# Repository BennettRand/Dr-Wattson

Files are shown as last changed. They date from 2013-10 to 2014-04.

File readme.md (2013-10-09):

#Dr. Wattson: Power Inspector#

##Project Description##
Dr. Wattson: Power Analyzer is an integrated system which aims brings real time data collection and analysis of home energy usage to consumers in an easy and understandable way. Presently, average consumers do not have the tools to make informed decisions about their energy consumption. The goal of the Dr. Wattson project is to help consumers evaluate their current energy consumption habits and provide them with recommendations to help them improve their energy footprint. Installation of the Dr. Wattson distributed network of distributed power monitors will be a simple plug and play process, making it simple to use for consumers of all technical abilities. Dr. Wattson will collect and process the user’s energy use habits and present them with easy to understand graphs, comparisons, and suggestions to help them save energy and money. Additionally, the user will be able to upload and compare their energy data with others via social networking.

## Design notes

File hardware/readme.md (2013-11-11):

##Hardware Files##
This directory is for storing the PCB design and schematic files.

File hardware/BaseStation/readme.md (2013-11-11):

##Hardware Files - Base Station##
PCB design files for the base station.

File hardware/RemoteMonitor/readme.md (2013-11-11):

##Hardware Files - Remote Monitoring Unit##
This is where we will store the design files for the remote monitoring unit PCB.

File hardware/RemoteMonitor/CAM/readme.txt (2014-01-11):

Remote Monitoring Unit PCB Design
Engineering Contact: Kit Morton <mortonki@onid.oregonstate.edu>
Board Outline is in top silkscreen layer (remoteMonitor.GTO)

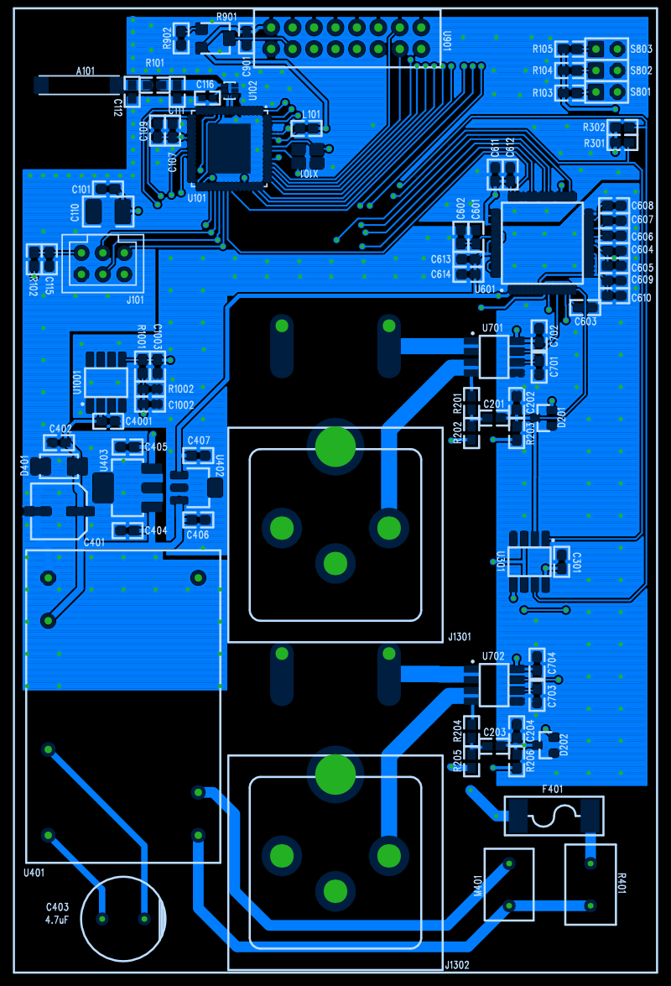
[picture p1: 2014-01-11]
hardware/RemoteMonitor/CAM/remoteMonitorTopLayer.png

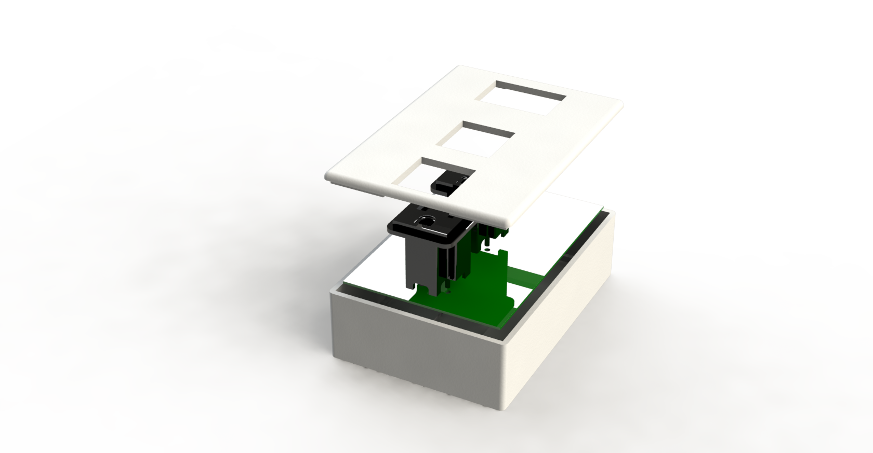
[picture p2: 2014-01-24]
hardware/RemoteMonitor/Case/exploded.png

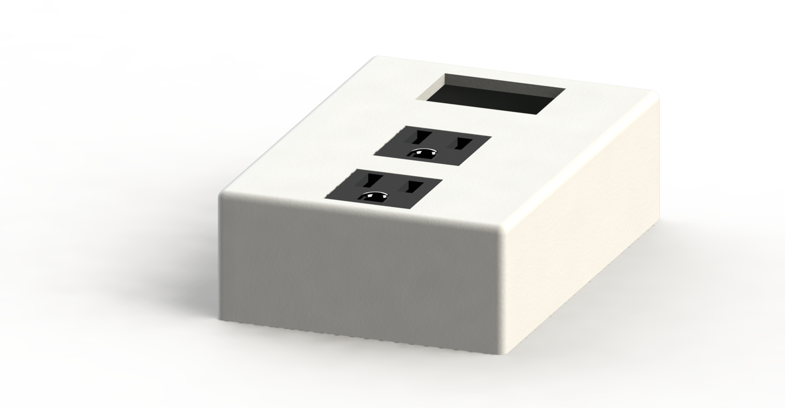
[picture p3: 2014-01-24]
hardware/RemoteMonitor/Case/case.png

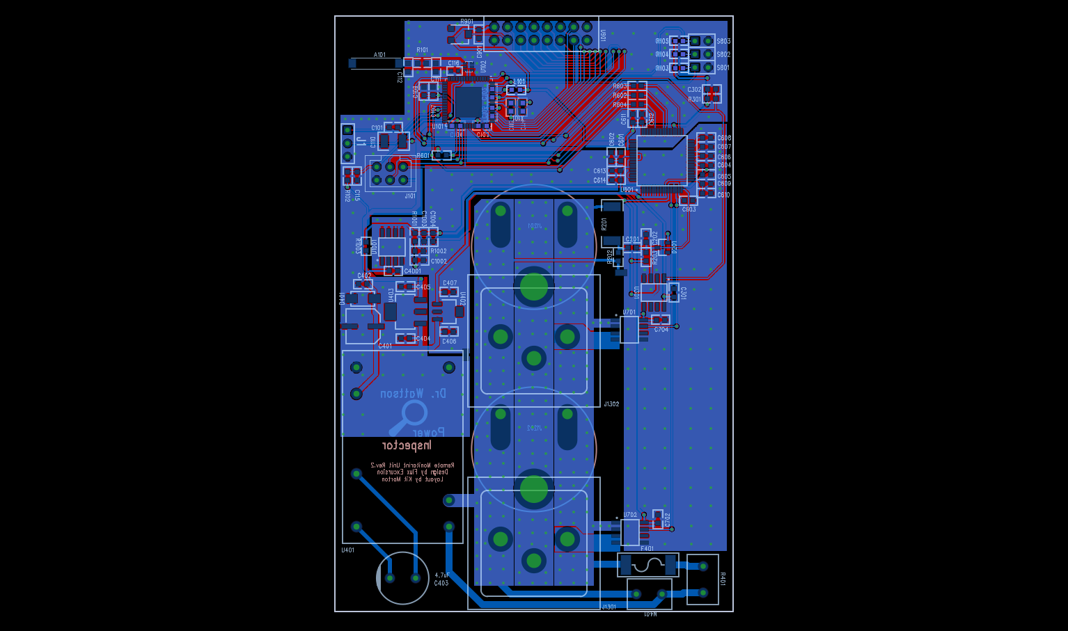
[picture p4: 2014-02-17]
hardware/RemoteMonitor/CAM/all_layers.png

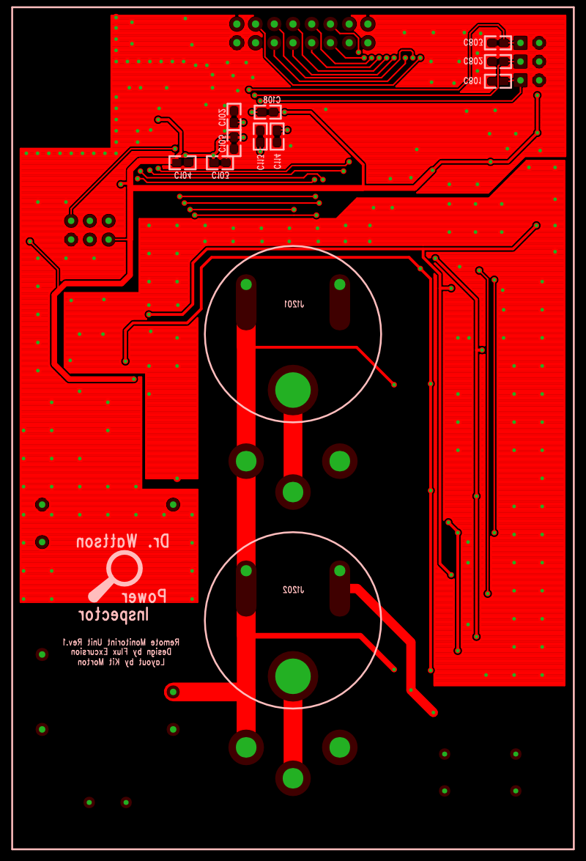
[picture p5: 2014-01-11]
hardware/RemoteMonitor/CAM/remoteMonitorBottomLayer.png

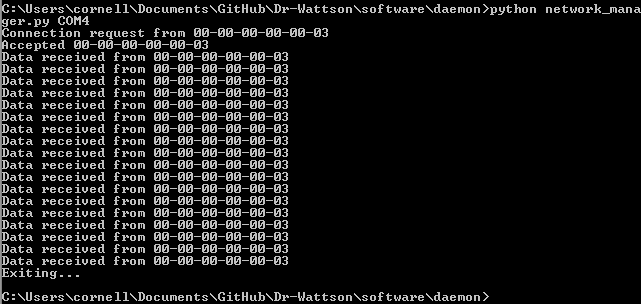
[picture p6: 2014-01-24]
software/daemon/console_demo.PNG

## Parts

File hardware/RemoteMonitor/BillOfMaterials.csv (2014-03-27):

Item | Qty | Reference | Part Name | Manufacturer | Description
1 | 1 | A101 | 2450AT45A100E
2 | 1 | U102 | 2450FB15L0001
3 | 1 | F401 | 3403.0163.11
4 | 3 | S801-803 | 40-4520-00
5 | 2 | U701-702 | ACS712
6 | 1 | U601 | ADS130E08IPAG
7 | 1 | U101 | ATMEGA256RFR2
8 | 1 | R401 | B57235S100M54
9 | 2 | D201-202 | BAT54S
10 | 1 | C116 | CAP0402 | 22pF | IPC SM-782 STD. | SURFACE MOUNT CAPACITOR 0.031 X 0.061 INCHES
11 | 20 | C101-102 C201 C203 C301 C402 C602-604 C610 C612-613 C702 C704 C801-803 C901 C1003 C4001 | CAP0603 | 0.1uF | IPC SM-782 STD. | SURFACE MOUNT CAPACITOR 0.031 X 0.061 INCHES
12 | 1 | C302 | CAP0603 | 10nF | IPC SM-782 STD. | SURFACE MOUNT CAPACITOR 0.031 X 0.061 INCHES
13 | 1 | C605 | CAP0603 | 10uF | IPC SM-782 STD. | SURFACE MOUNT CAPACITOR 0.031 X 0.061 INCHES
14 | 3 | C113-115 | CAP0603 | 16pF | IPC SM-782 STD. | SURFACE MOUNT CAPACITOR 0.031 X 0.061 INCHES
15 | 18 | C103-105 C107-109 C404-407 C601 C606 C608-609 C611 C614 C1002 C1004 | CAP0603 | 1uF | IPC SM-782 STD. | SURFACE MOUNT CAPACITOR 0.031 X 0.061 INCHES
16 | 1 | C607 | CAP0603 | 22uF | IPC SM-782 STD. | SURFACE MOUNT CAPACITOR 0.031 X 0.061 INCHES
17 | 2 | C202 C204 | CAP0603 | 4.7nF | IPC SM-782 STD. | SURFACE MOUNT CAPACITOR 0.031 X 0.061 INCHES
18 | 2 | C111-112 | CAP0603 | N/A | IPC SM-782 STD. | SURFACE MOUNT CAPACITOR 0.031 X 0.061 INCHES
19 | 1 | C110 | CAP1210 | 47uF | IPC SM-782 STD. | SURFACE MOUNT CAPACITOR 0.098 X 0.126 INCHES
20 | 1 | C403 | CAP-D10P | 4.7uF
21 | 1 | C401 | EEE-FTV151 | 150uF
22 | 1 | M401 | ERZ-V07D471
23 | 1 | L101 | FERRITE
24 | 1 | J1 | HEADER03 |  | THREE PIN INLINE HEADER; 100 MIL CENTERS
25 | 1 | J101 | ISP_HEADER
26 | 1 | U402 | L78L05
27 | 1 | U301 | LM2903-TI
28 | 2 | J1301-1302 | NEMA-5-15R
29 | 2 | J1201-1202 | NEMA5-15P
30 | 1 | U901 | NHD-0208AZ-RN-YBW-33V
31 | 1 | D401 | P4SMA20A
32 | 1 | R901 | PVG3A | 10K
33 | 1 | U1001 | REF02BU
34 | 1 | R101 | RES0603 | 0 | IPC SM-782 STD. | SURFACE MOUNT RESISTOR 0.031 X 0.061 INCHES | 1/10W
35 | 6 | R102-105 R301 R601 | RES0603 | 10K | IPC SM-782 STD. | SURFACE MOUNT RESISTOR 0.031 X 0.061 INCHES | 1/10W
36 | 2 | R203 R206 | RES0603 | 1M | IPC SM-782 STD. | SURFACE MOUNT RESISTOR 0.031 X 0.061 INCHES | 1/10W
37 | 2 | R1001-1002 | RES0603 | 2.2k | IPC SM-782 STD. | SURFACE MOUNT RESISTOR 0.031 X 0.061 INCHES | 1/10W
38 | 2 | R202 R205 | RES0603 | 2K | IPC SM-782 STD. | SURFACE MOUNT RESISTOR 0.031 X 0.061 INCHES | 1/10W
39 | 1 | R1003 | RES0603 | 330 | IPC SM-782 STD. | SURFACE MOUNT RESISTOR 0.031 X 0.061 INCHES | 1/10W
40 | 2 | R602-603 | RES0603 | 470 | IPC SM-782 STD. | SURFACE MOUNT RESISTOR 0.031 X 0.061 INCHES | 1/10W
41 | 2 | R201 R204 | RES2512 | 330K | IPC SM-782 STD. | SURFACE MOUNT RESISTOR 0.126 X 0.248 INCHES | 1W
42 | 3 | S1-3 | SHORT
43 | 1 | X101 | TSX-3225_16.0000
44 | 1 | U403 | UA78M33
45 | 1 | U401 | VSK-S3-12U

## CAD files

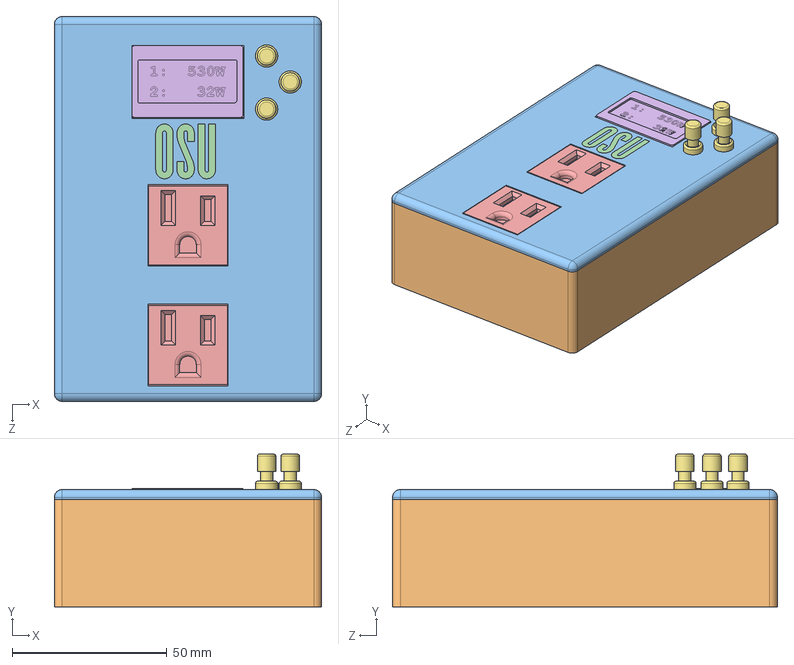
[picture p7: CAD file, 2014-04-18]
hardware/RemoteMonitor/Case/case.SLDASM
86.4 x 49.4 x 124.3 mm
pcb
base
cover
logo
plug x 2
Screen
Switch x 3

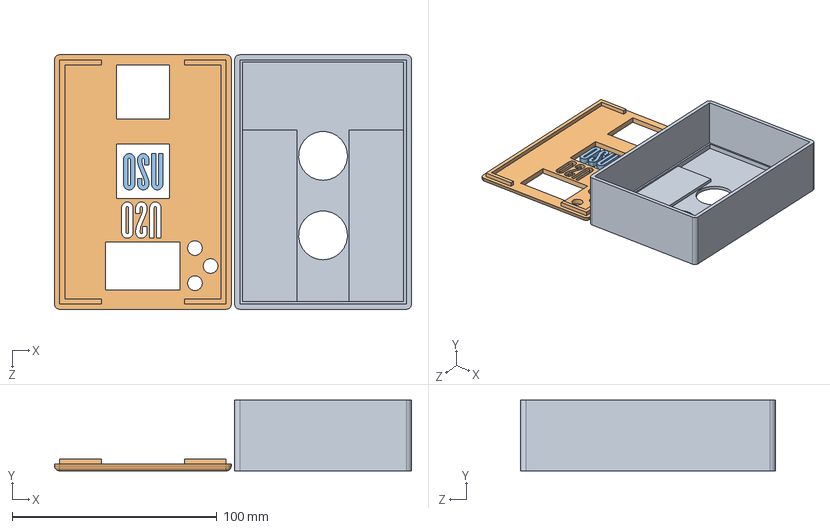
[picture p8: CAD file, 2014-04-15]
hardware/RemoteMonitor/Case/printed.SLDASM
174.3 x 34.6 x 124.3 mm
base
cover
logo

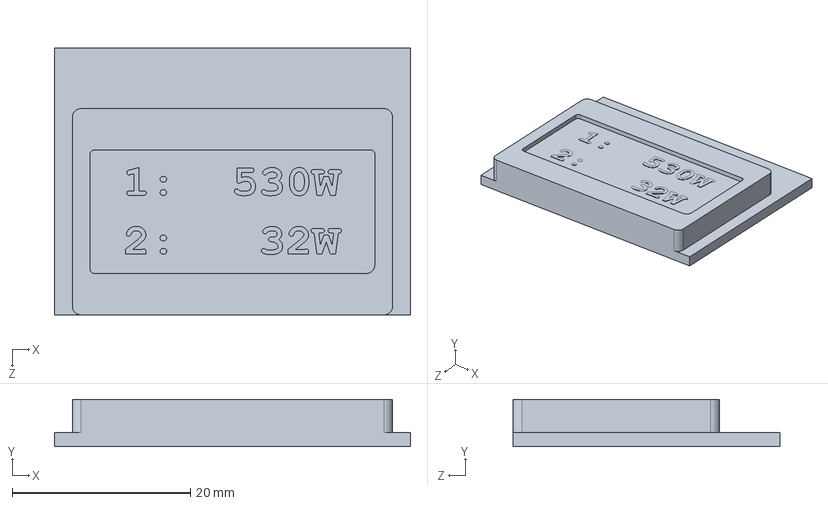
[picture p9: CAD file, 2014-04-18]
hardware/RemoteMonitor/Case/Screen.SLDPRT
40.0 x 5.30 x 30.0 mm

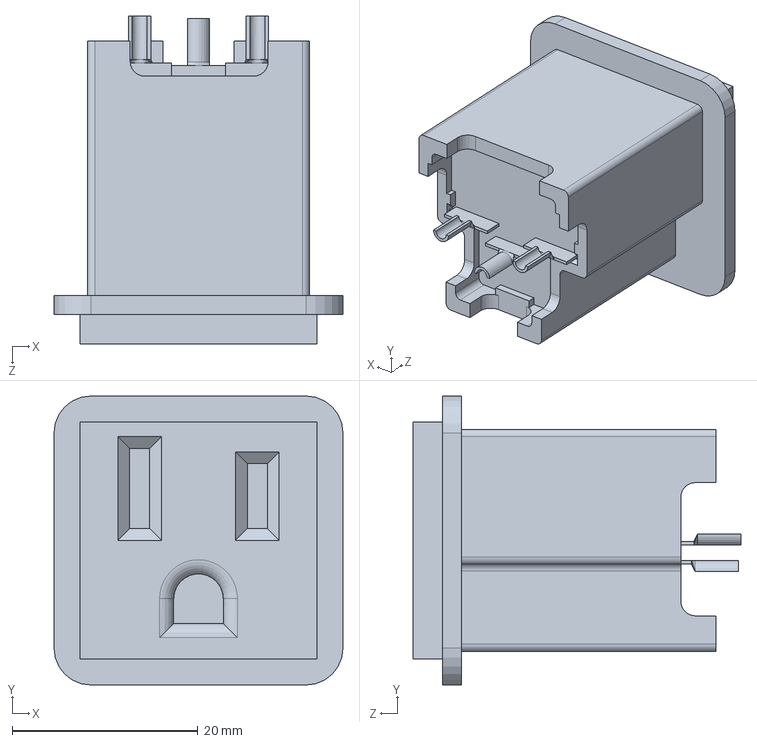
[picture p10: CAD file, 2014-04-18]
hardware/RemoteMonitor/Case/plug.SLDPRT
31.1 x 31.1 x 35.3 mm

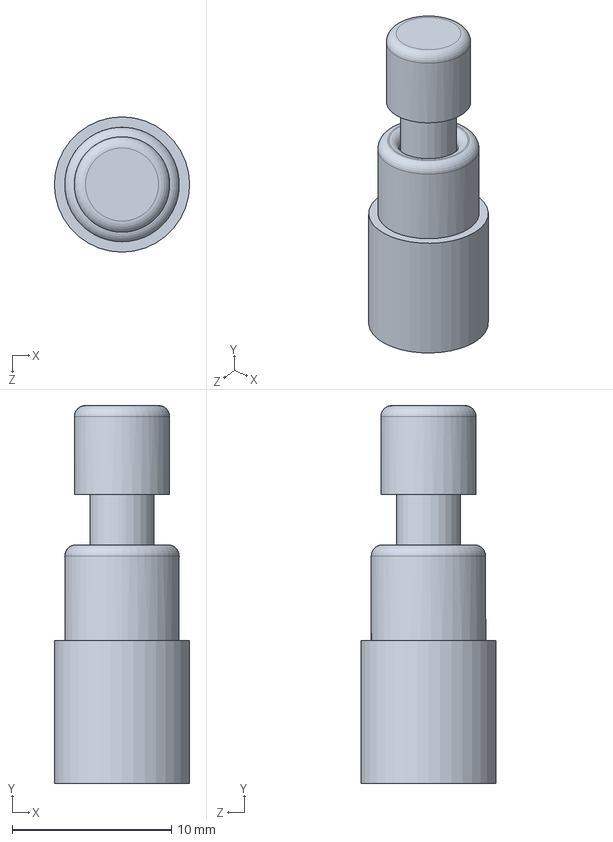
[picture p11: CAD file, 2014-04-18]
hardware/RemoteMonitor/Case/Switch.SLDPRT
8.50 x 23.8 x 8.50 mm

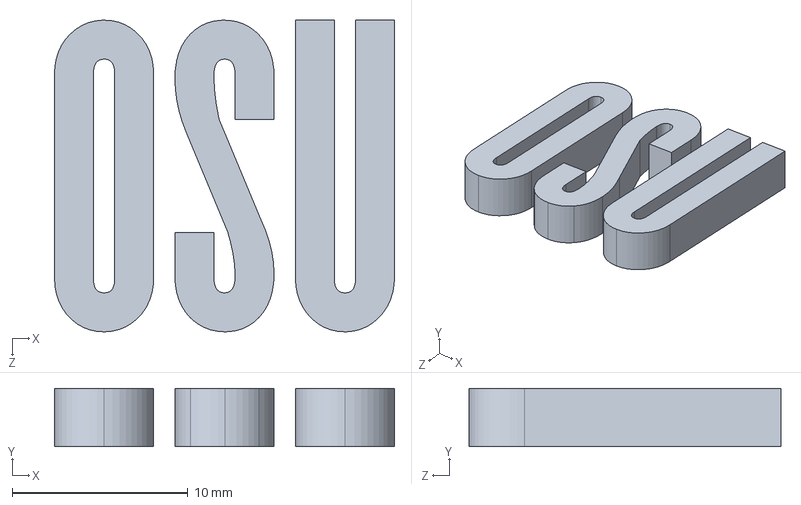
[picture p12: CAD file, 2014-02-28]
hardware/RemoteMonitor/Case/logo.SLDPRT
19.3 x 3.30 x 17.7 mm

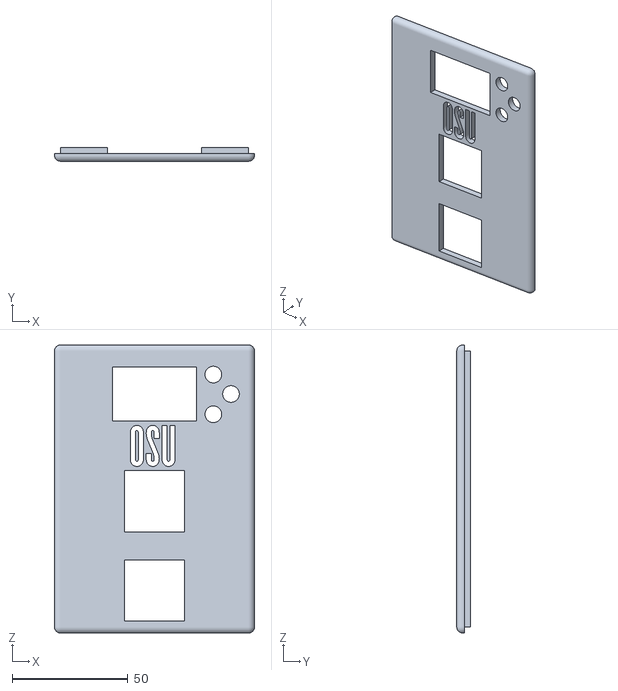
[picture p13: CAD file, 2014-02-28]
hardware/RemoteMonitor/Case/printed - cover-1.STL
86.4 x 5.84 x 124.3

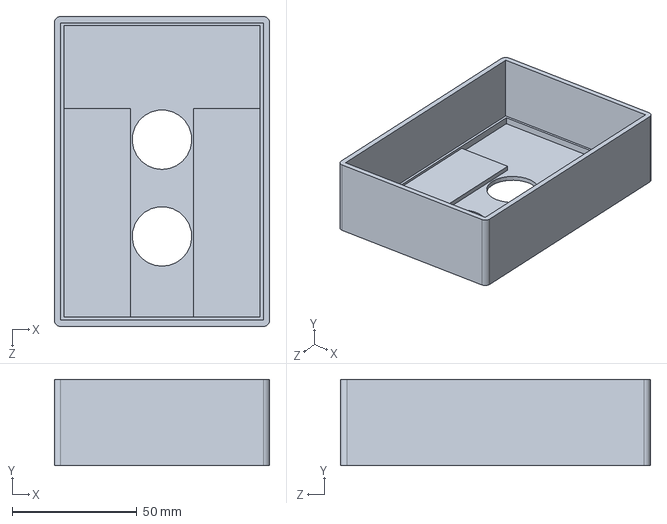
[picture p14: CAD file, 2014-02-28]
hardware/RemoteMonitor/Case/base.SLDPRT
86.4 x 34.6 x 124.3 mm

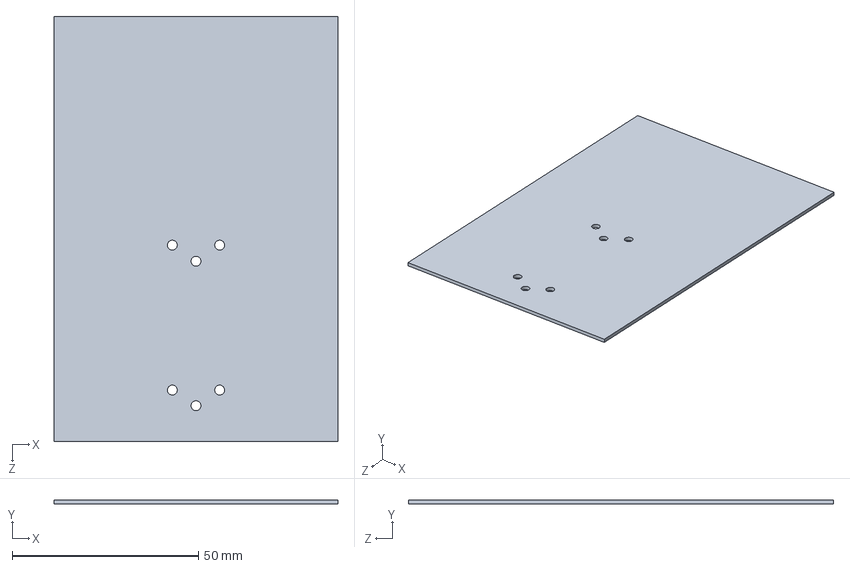
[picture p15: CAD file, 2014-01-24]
hardware/RemoteMonitor/Case/pcb.SLDPRT
76.2 x 1.12 x 114.2 mm

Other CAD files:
hardware/RemoteMonitor/Case/cover.SLDPRT
hardware/RemoteMonitor/Case/printed - logo-1.STL
hardware/RemoteMonitor/Case/printed - base-1.STL
hardware/RemoteMonitor/Case/c-3-213598-2-m-3d.stp
hardware/RemoteMonitor/Case/printed.STL

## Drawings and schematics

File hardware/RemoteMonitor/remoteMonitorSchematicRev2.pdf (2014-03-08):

D

6 | 5 | 4 | 3 | 2 | 1

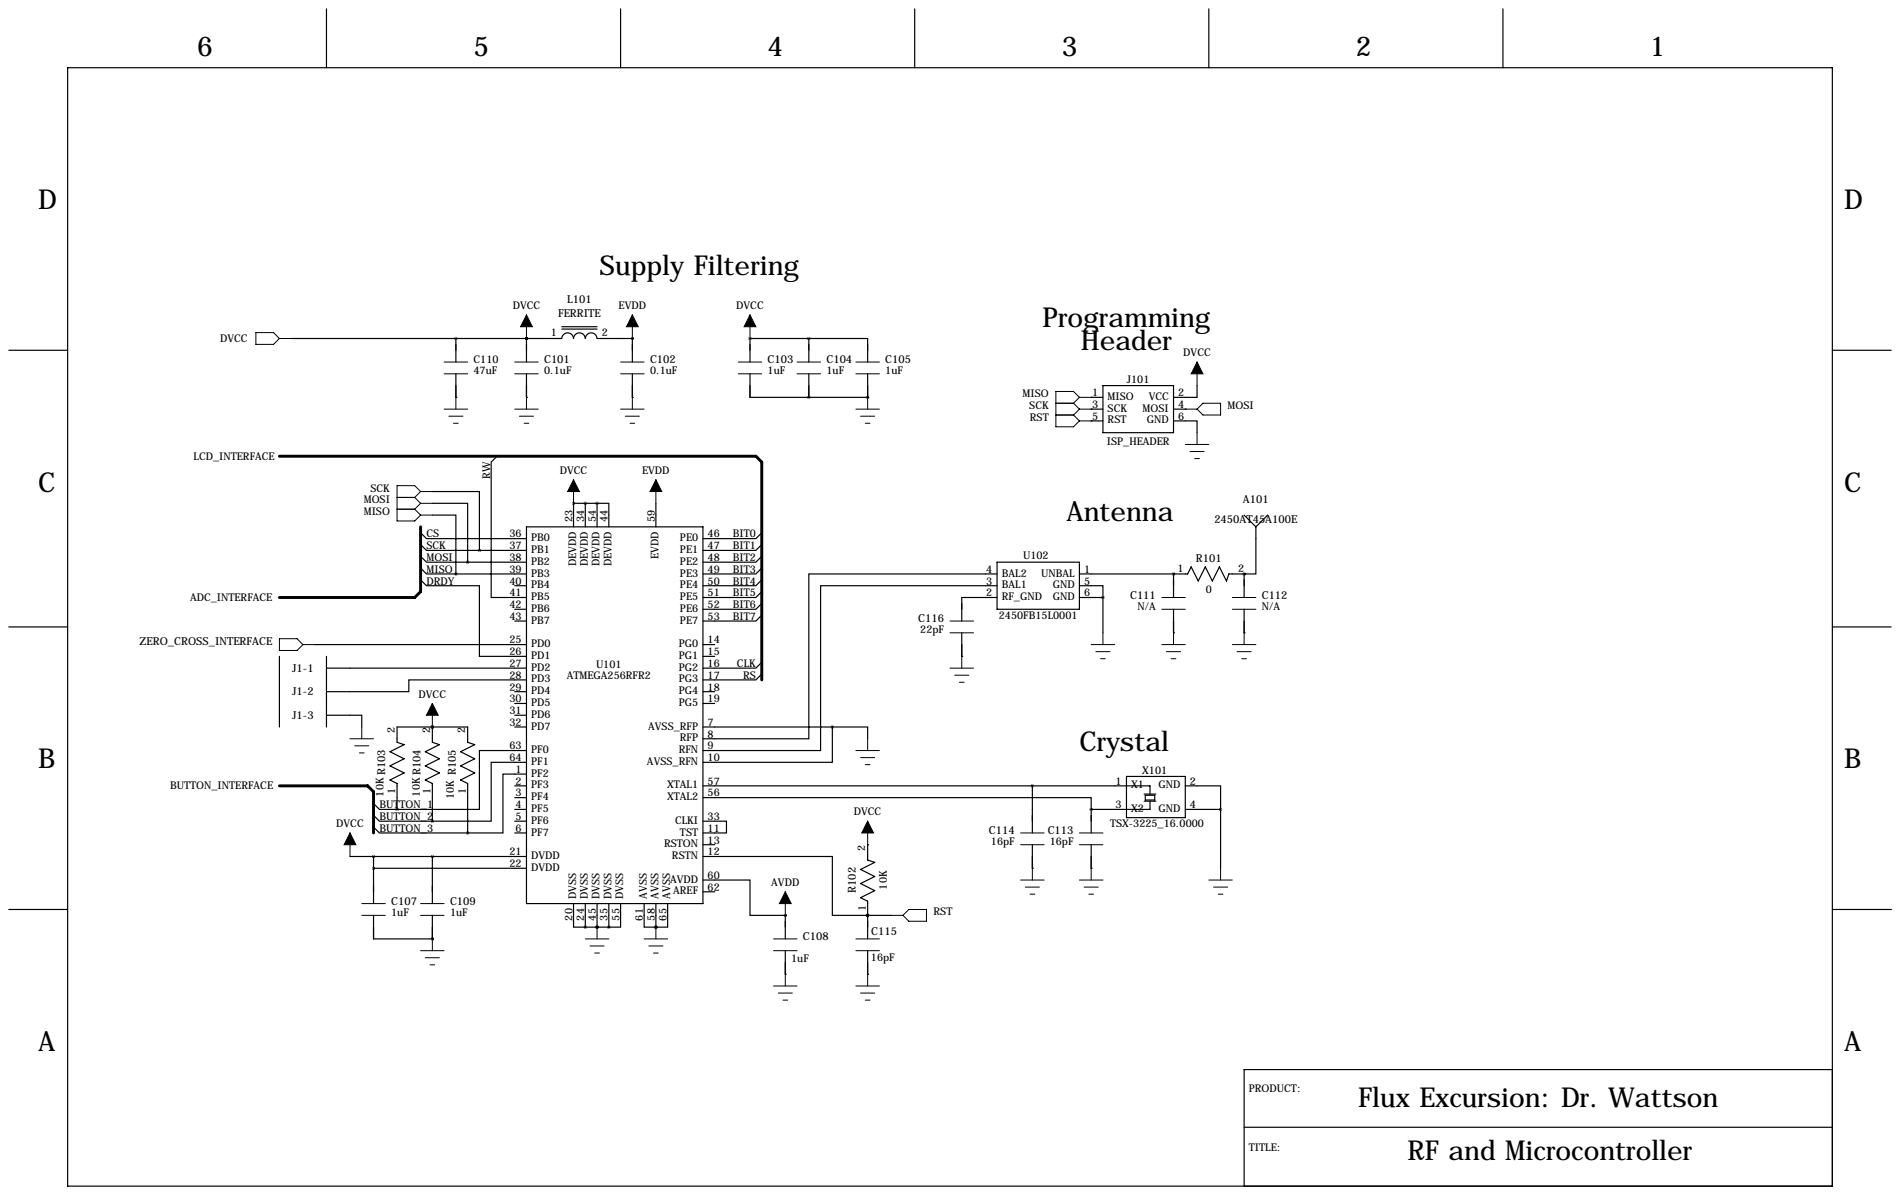
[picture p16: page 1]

D

D

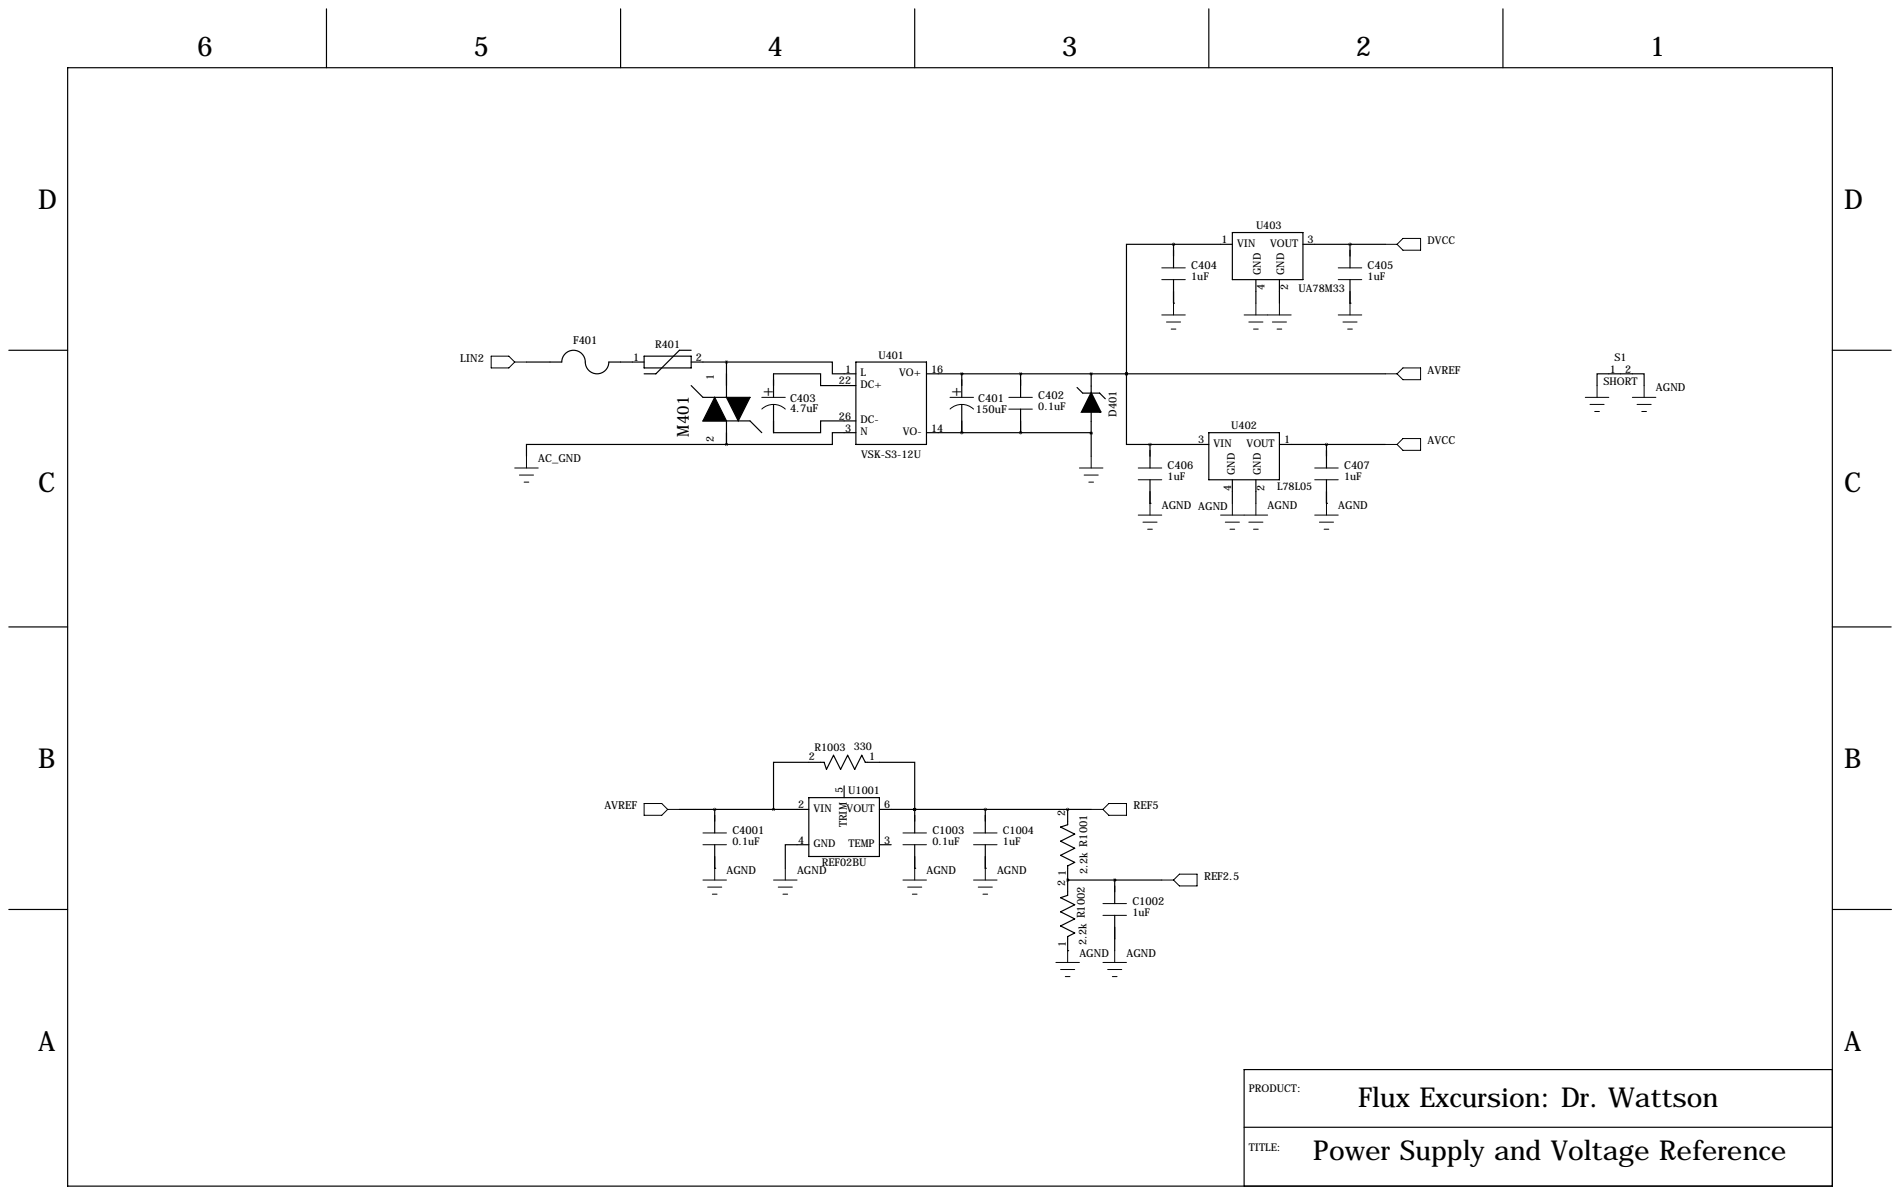
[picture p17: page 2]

Flux Excursion: Dr. Wattson PRODUCT:

Power Supply and Voltage Reference

D

D

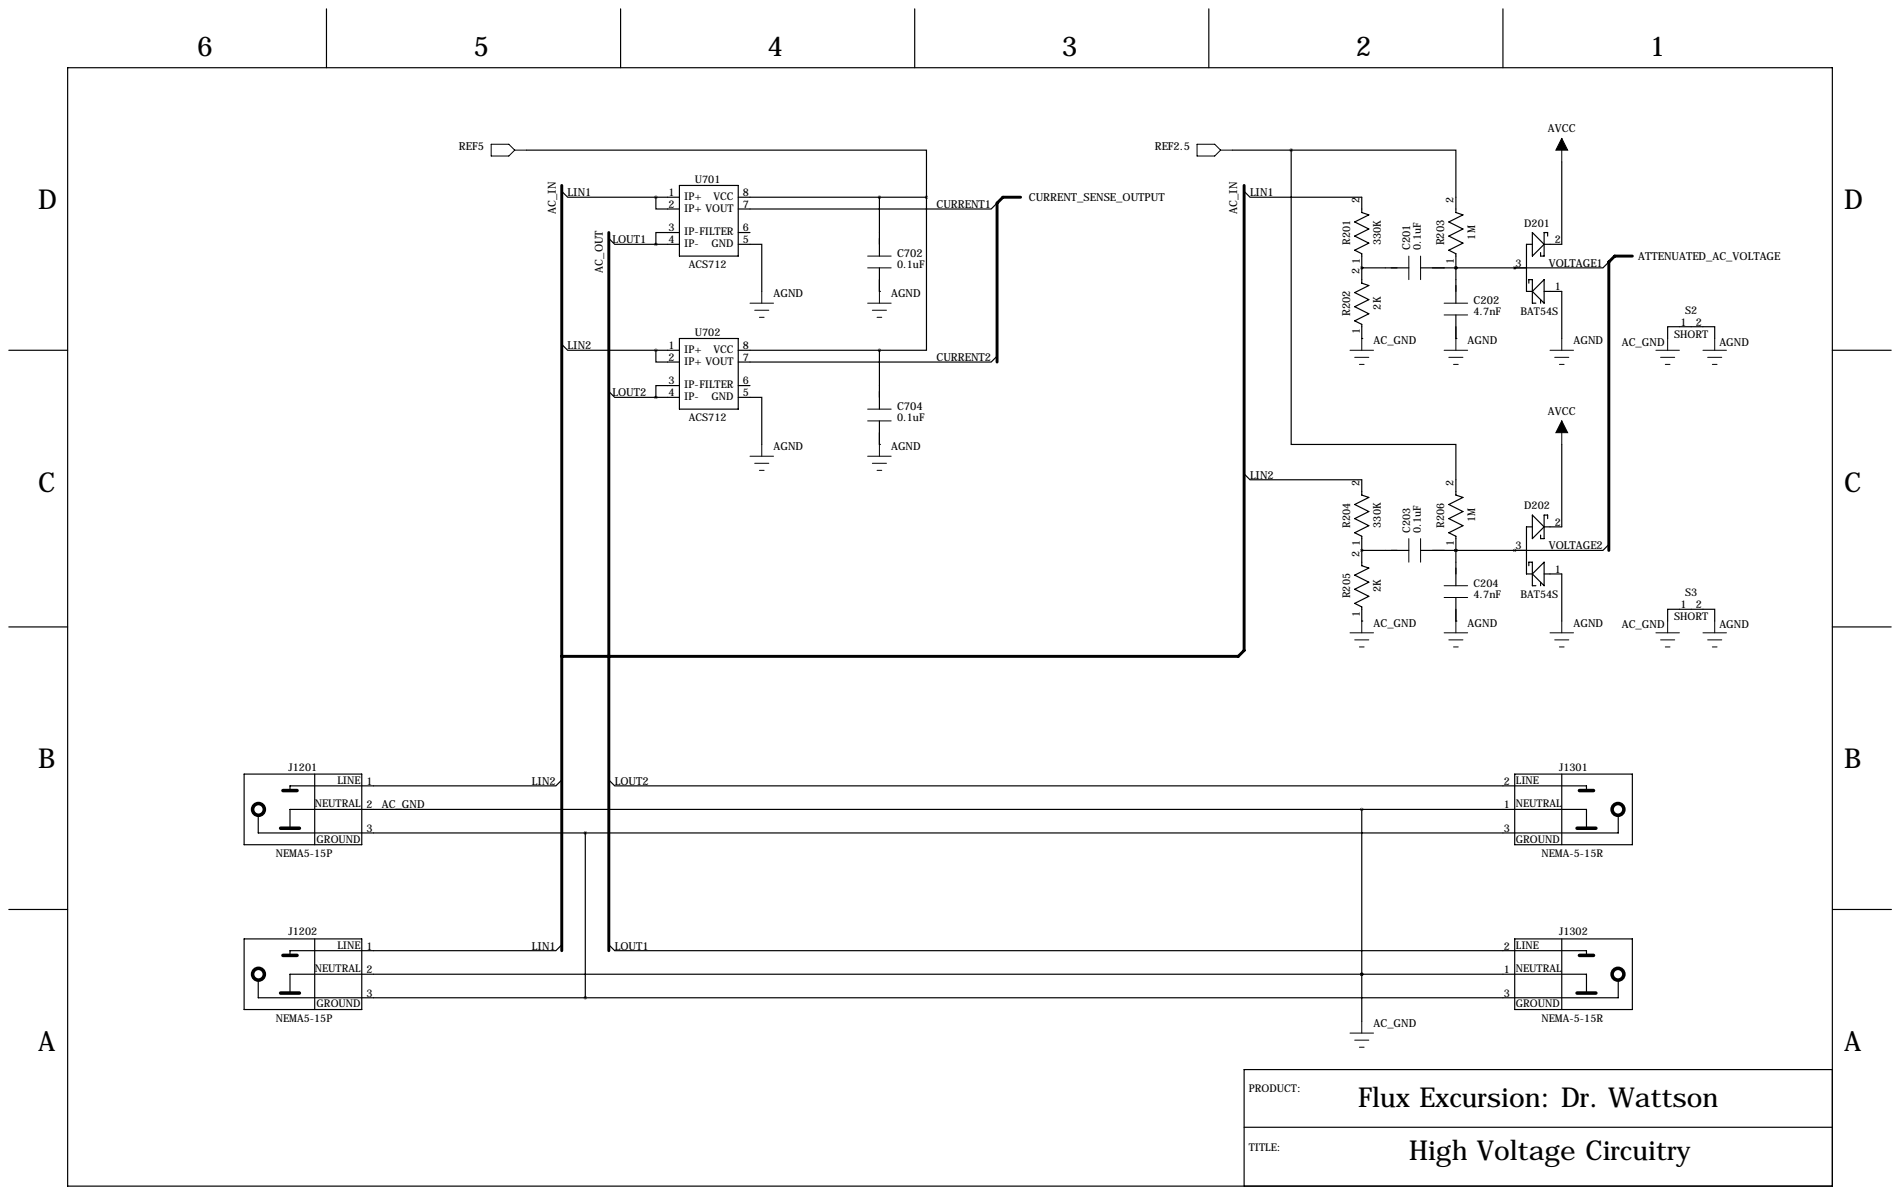
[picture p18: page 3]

D

D

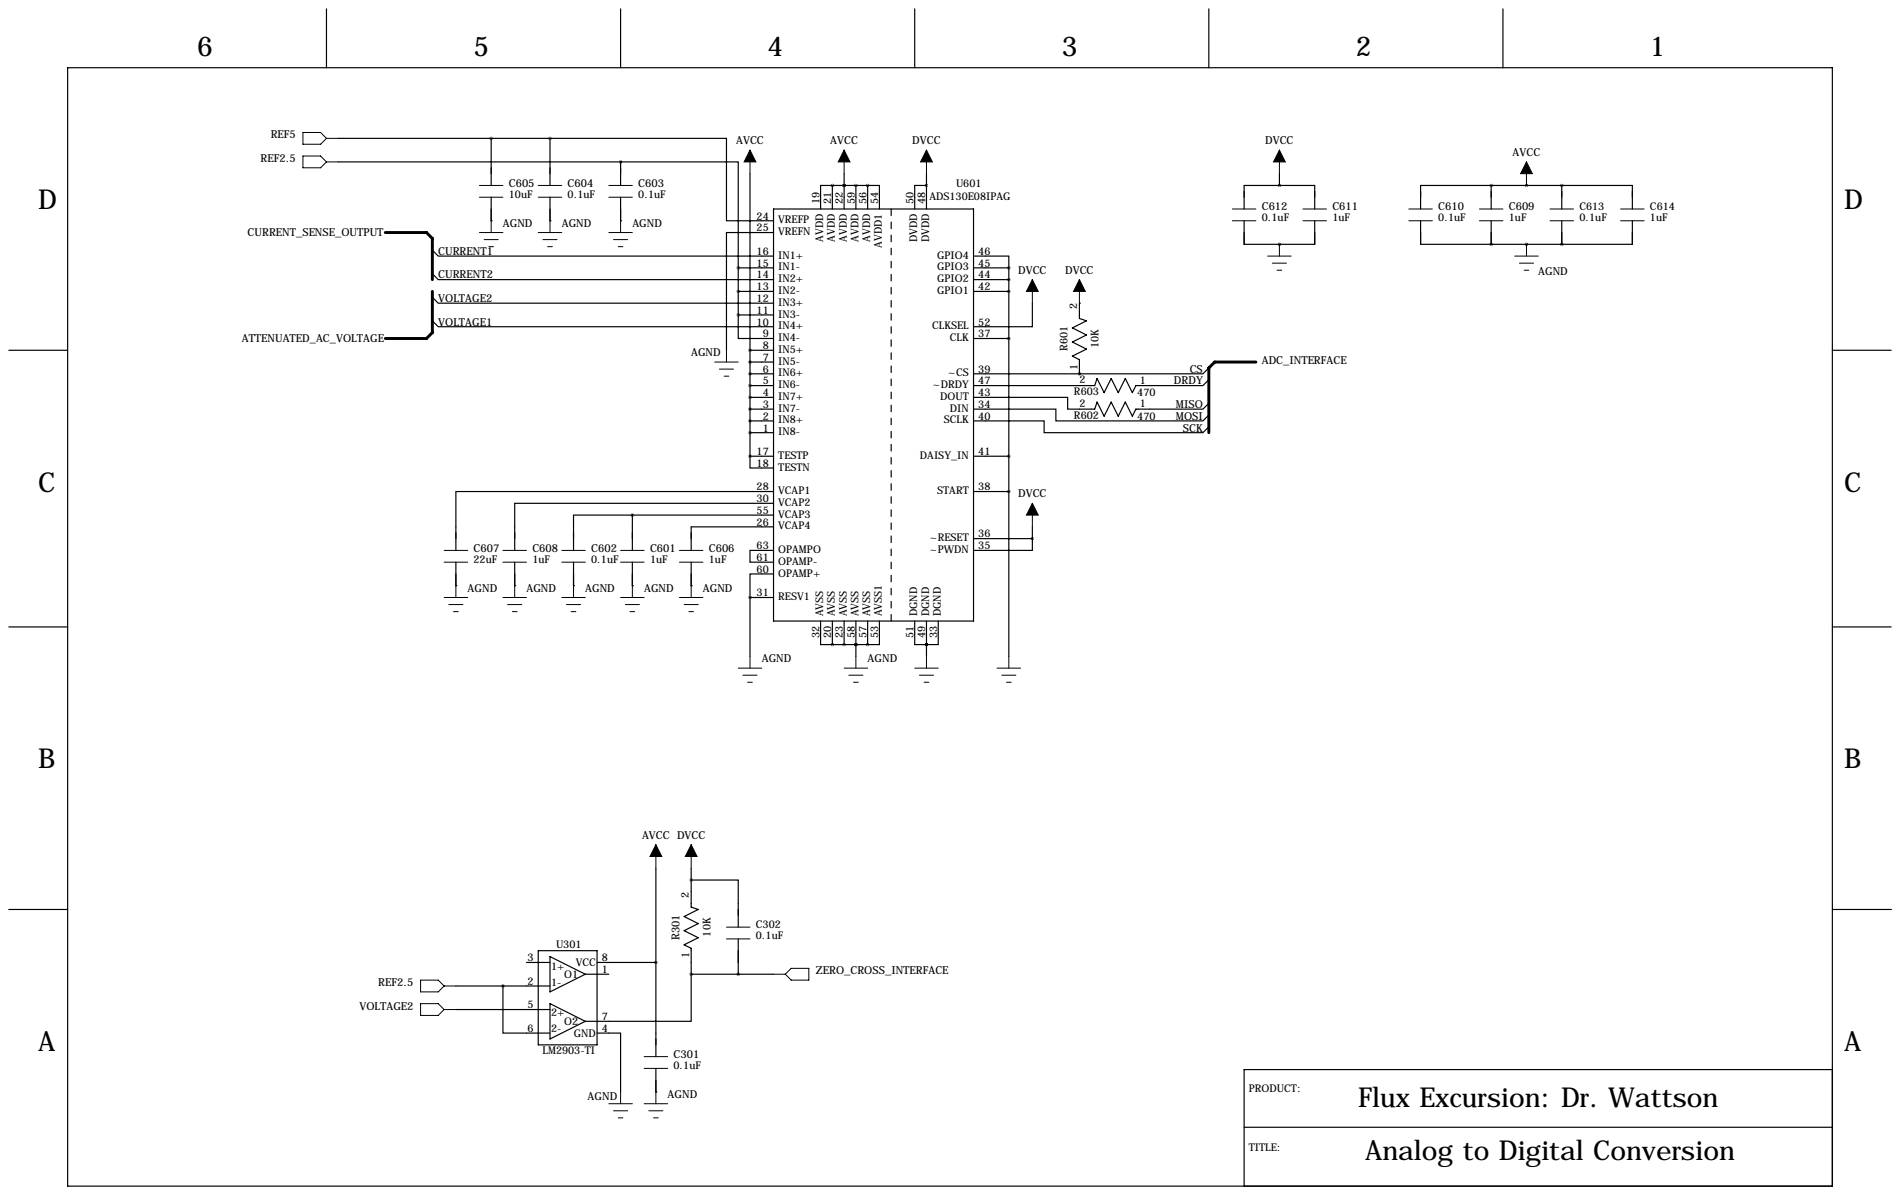
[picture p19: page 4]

Flux Excursion: Dr. Wattson PRODUCT:

Analog to Digital Conversion

D

D

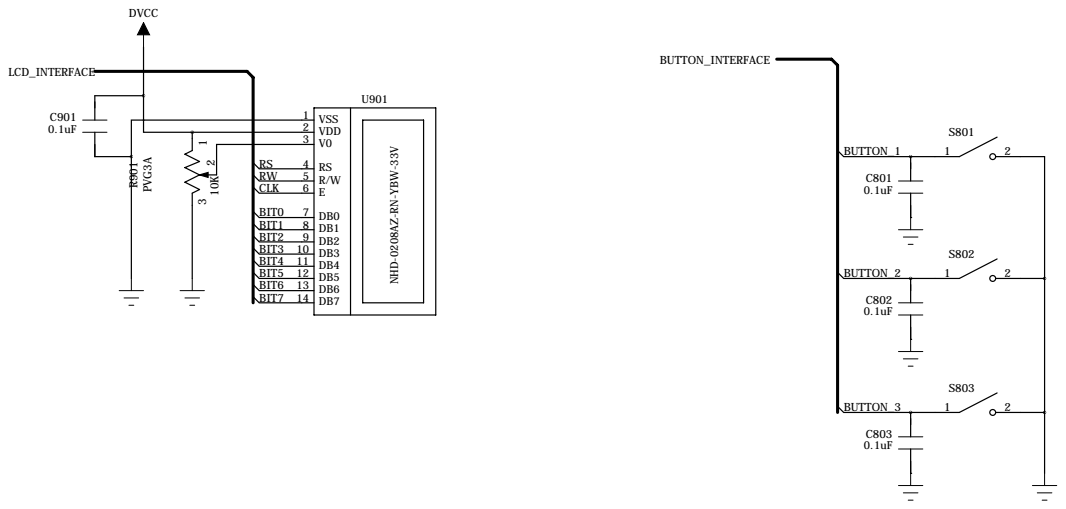
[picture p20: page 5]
PRODUCT:; Flux Excursion: Dr. Wattson; PVG3A; VSS; VDD; DVCC; LCD_INTERFACE; BIT0 BIT1 BIT2 BIT3 BIT4 BIT5 BIT6 BIT7; CLK; BUTTON_INTERFACE; BUTTON_1; BUTTON_2; BUTTON_3

NHD-0208AZ-RN-YBW-33V

Screen and Buttons

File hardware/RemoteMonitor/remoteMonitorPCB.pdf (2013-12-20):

U101 L101

A101 | U102

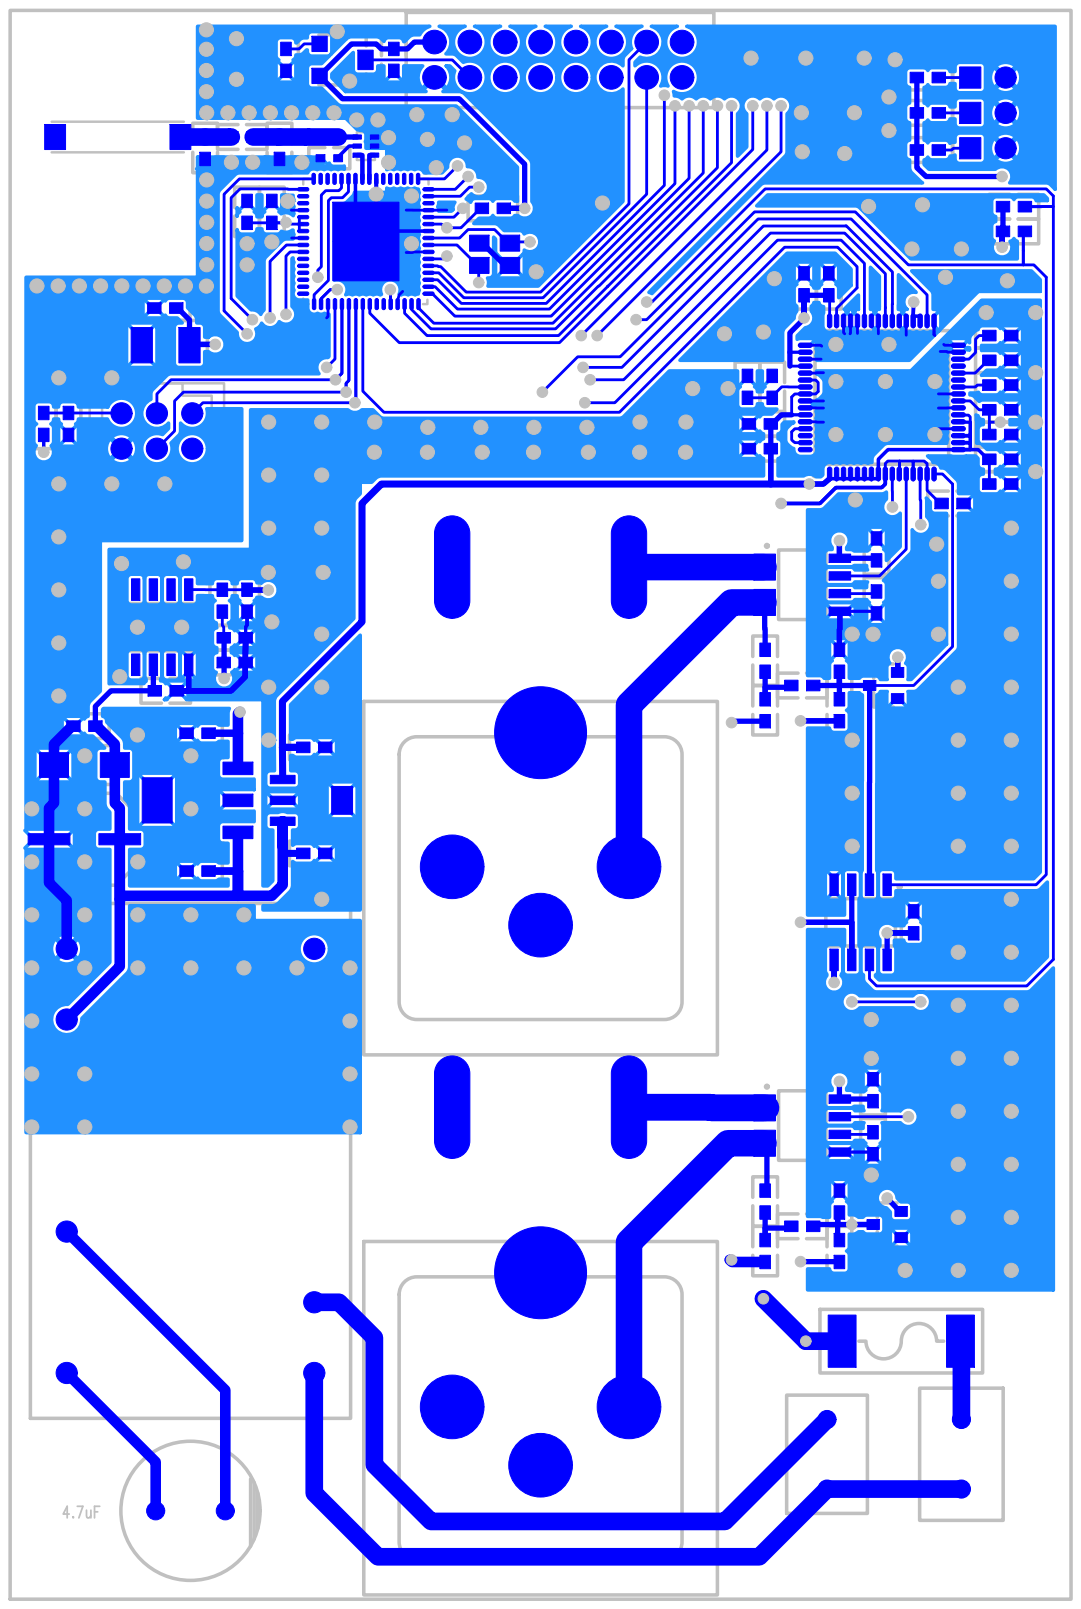
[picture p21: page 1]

# C105C¹⁰⁵x1 C¹⁰⁵x2

# C108 C¹⁰⁸x1 C¹⁰⁸x2

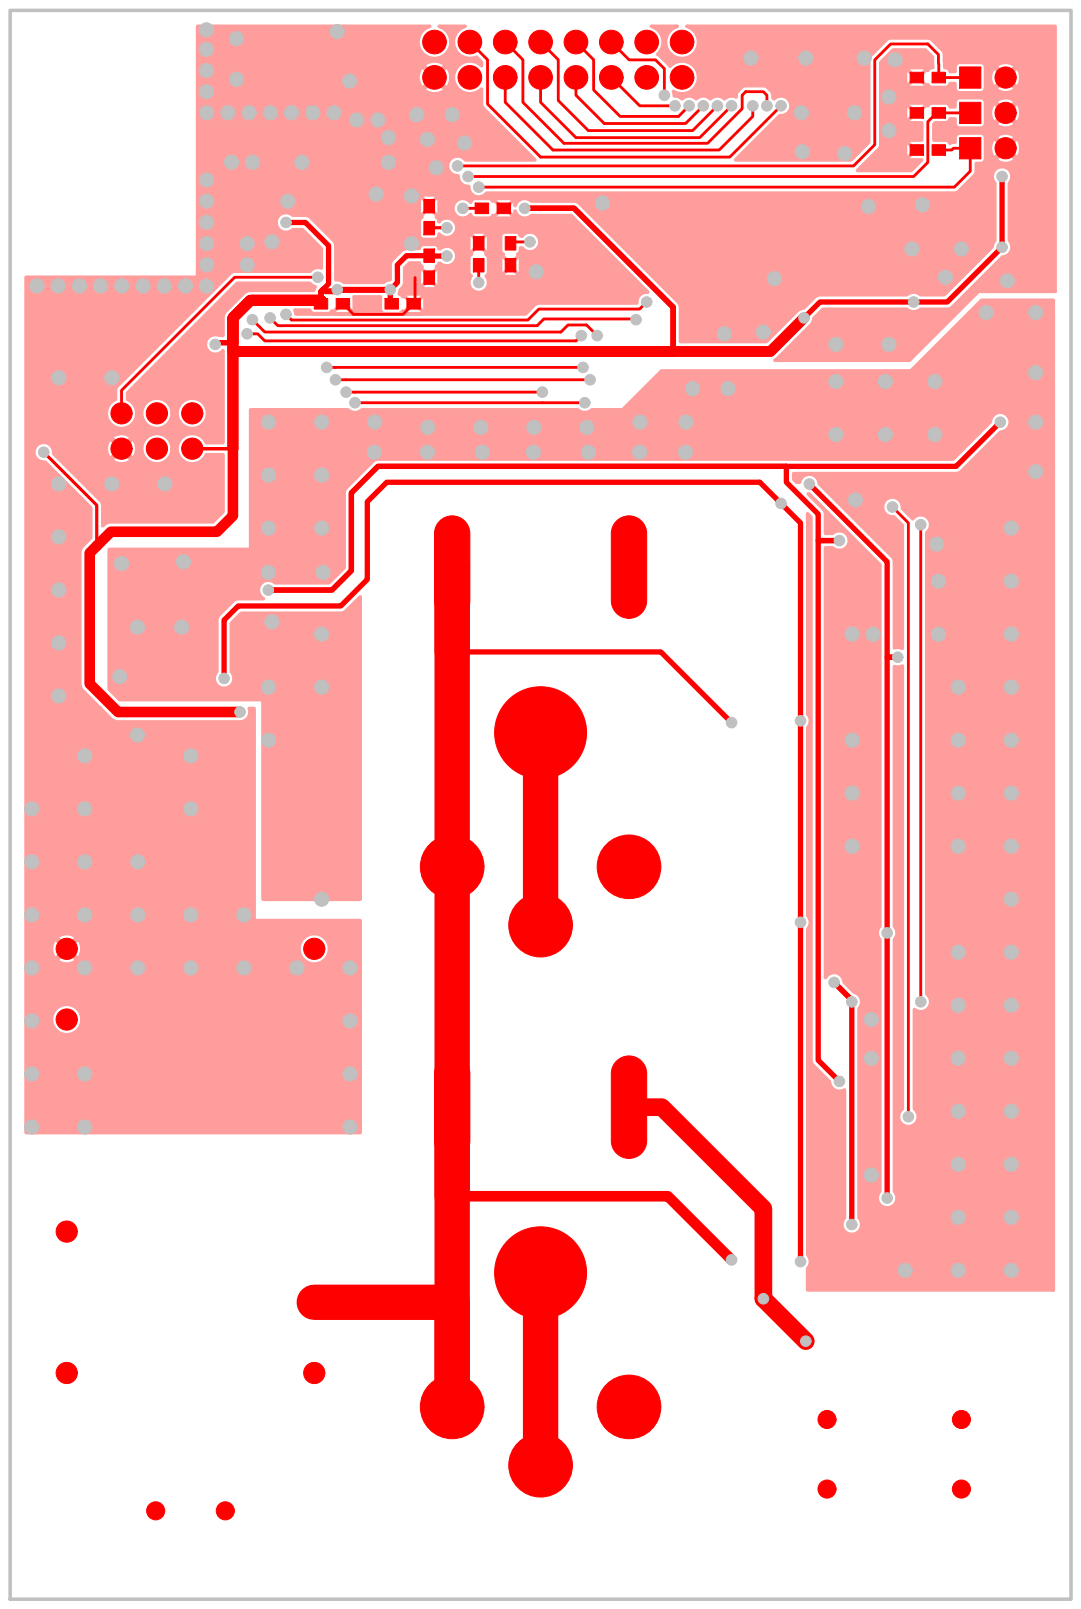
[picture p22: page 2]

L101

A101

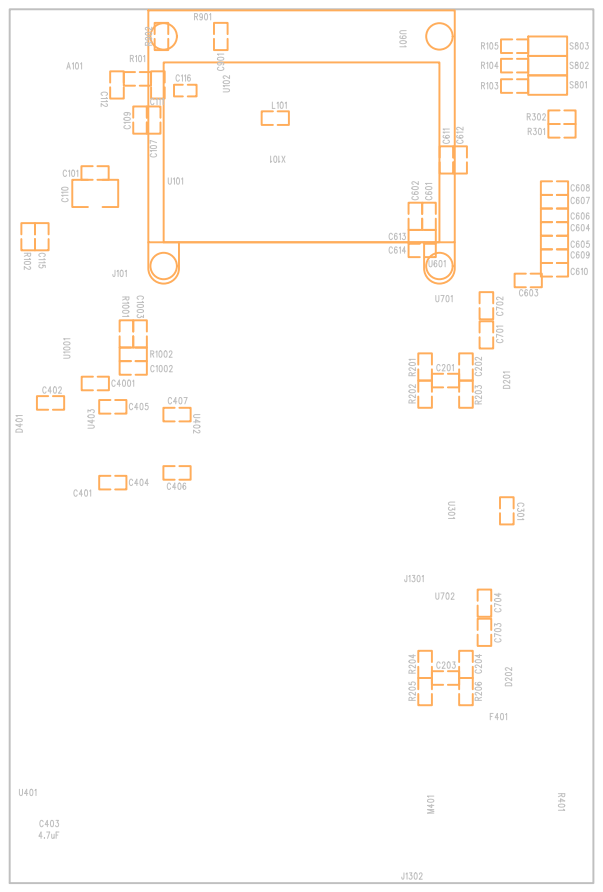
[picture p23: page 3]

C801

C802

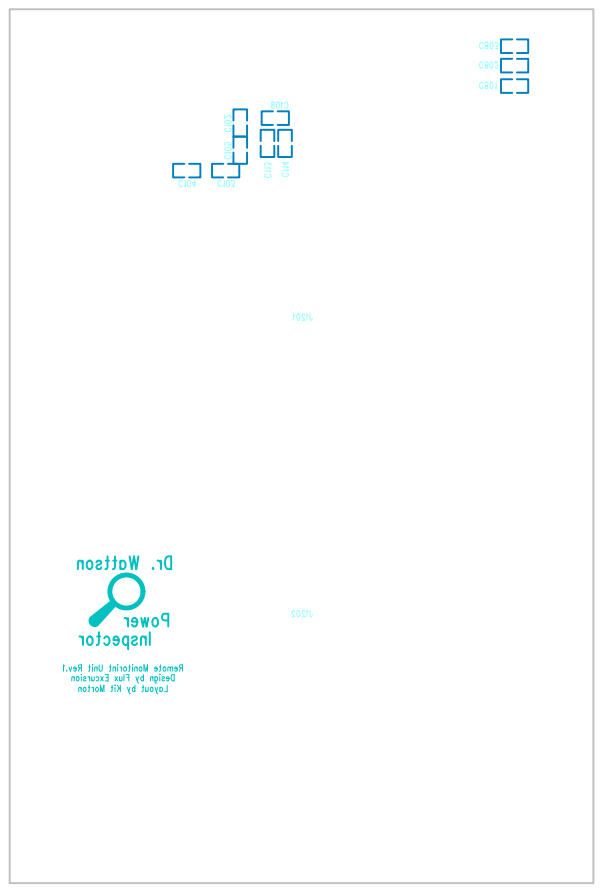
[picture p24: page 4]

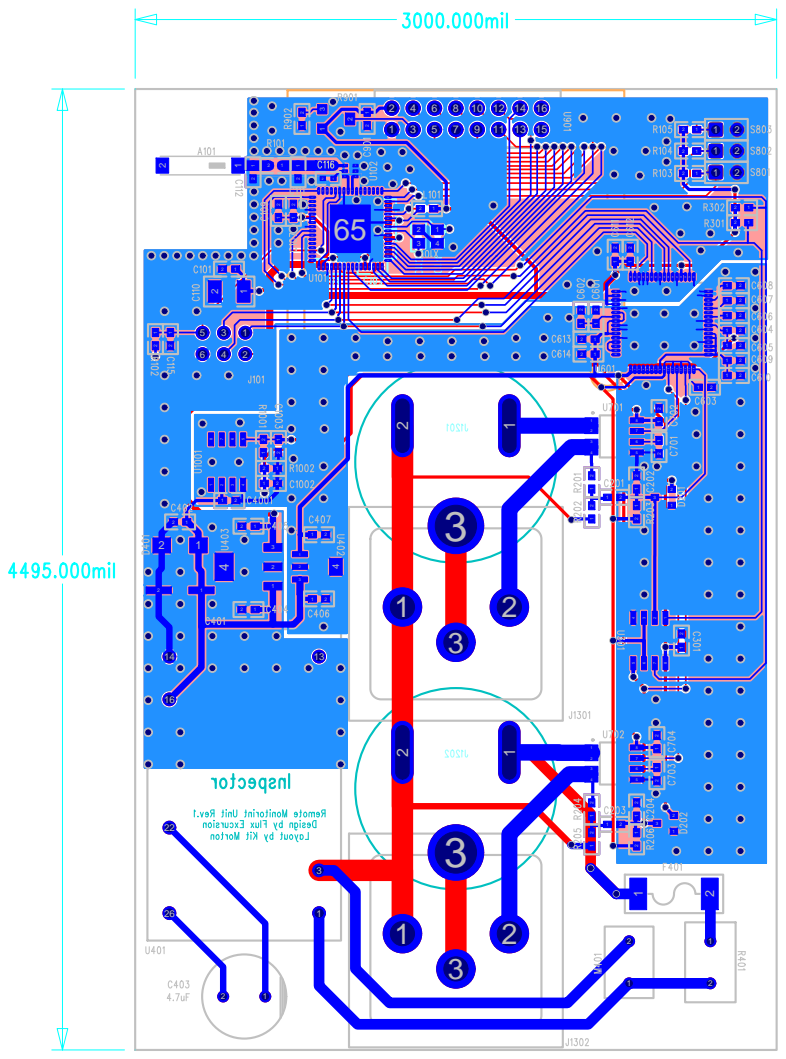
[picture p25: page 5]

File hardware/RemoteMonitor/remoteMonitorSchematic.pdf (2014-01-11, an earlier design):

D

6 | 5 | 4 | 3 | 2 | 1

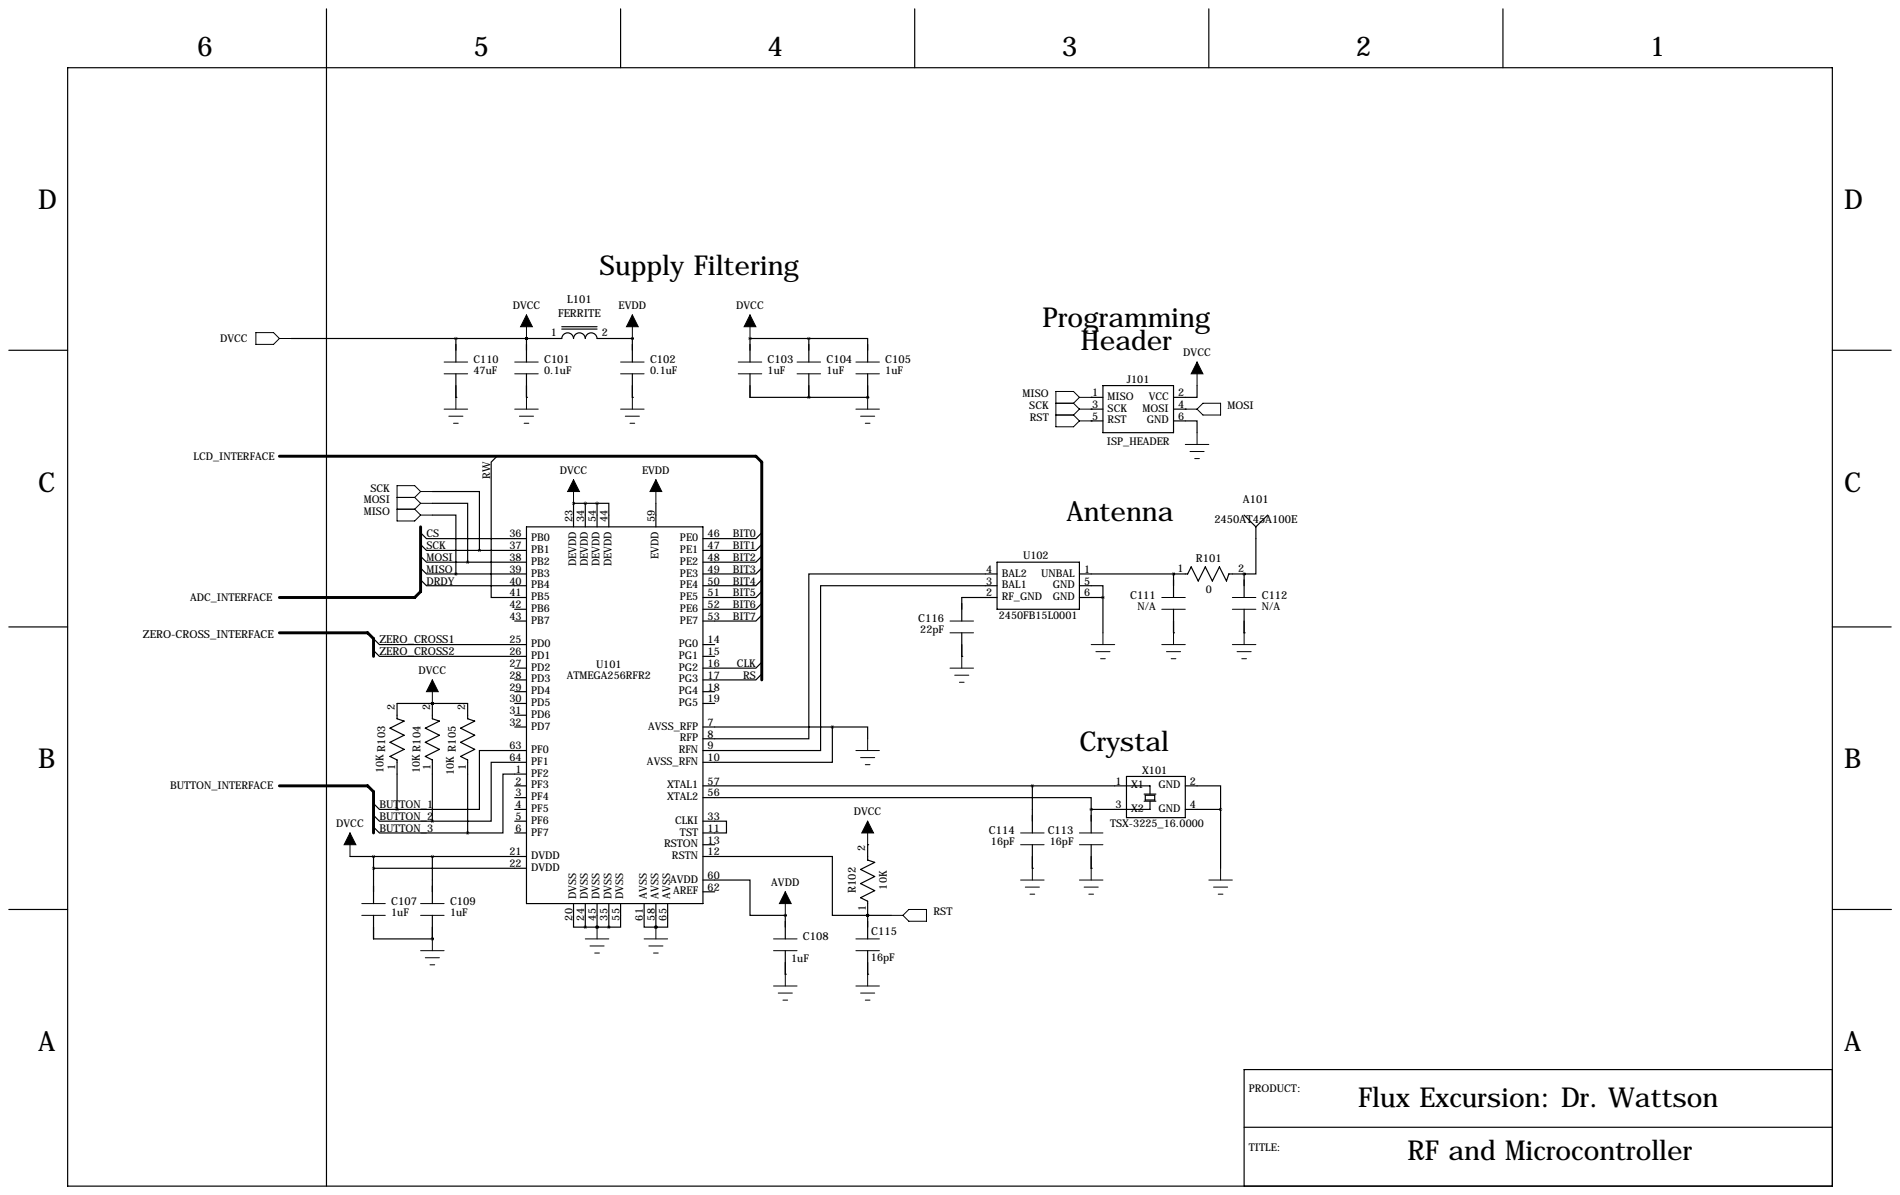
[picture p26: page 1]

D

D

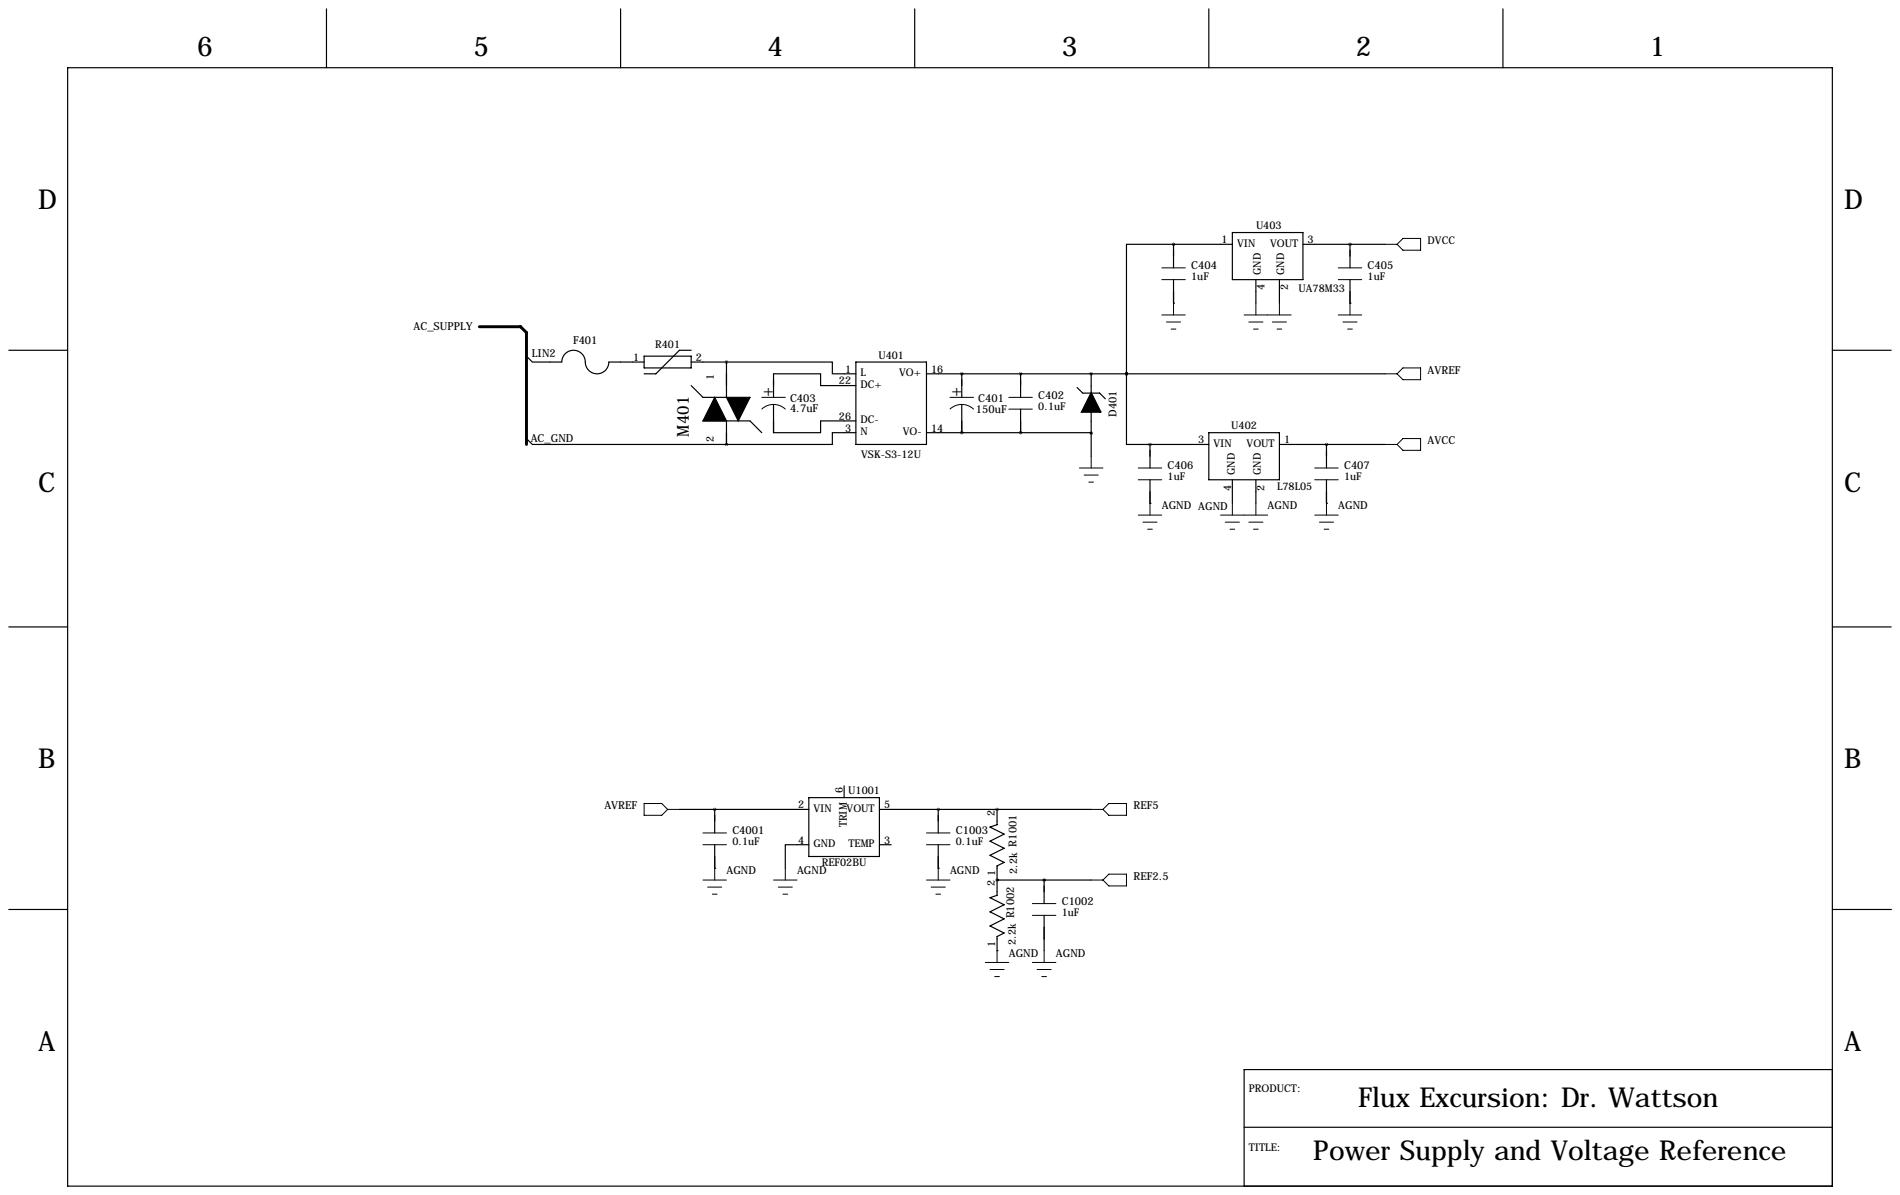
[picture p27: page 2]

Flux Excursion: Dr. Wattson PRODUCT:

Power Supply and Voltage Reference

D

D


D

D


Flux Excursion: Dr. Wattson PRODUCT:

Analog to Digital Conversion

D

D

PRODUCT:; Flux Excursion: Dr. Wattson; PVG3A; VSS; VDD; DVCC; LCD_INTERFACE; BIT0 BIT1 BIT2 BIT3 BIT4 BIT5 BIT6 BIT7; CLK; BUTTON_INTERFACE; BUTTON_1; BUTTON_2; BUTTON_3

NHD-0208AZ-RN-YBW-33V

Screen and Buttons

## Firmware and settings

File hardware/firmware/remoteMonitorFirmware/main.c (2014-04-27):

#include <avr/io.h>
#include <avr/boot.h>
#include <avr/eeprom.h>
#include <util/delay.h>
#include <stdint.h>

#include "config.h"
#include "hal.h"
#include "phy.h"
#include "sys.h"
#include "nwk.h"

#include "protocol.h"
#include "basestation.h"
#include "dataAck.h"
#include "ui.h"
#include "lcd.h"

NWK_DataReq_t nwkPacket[DATA_REQ_BUFFER_CNT];
bool dataReqBusy[DATA_REQ_BUFFER_CNT];
uint8_t retransmit_cnt[DATA_REQ_BUFFER_CNT];
uint16_t retransmit_time[DATA_REQ_BUFFER_CNT];

dataRequestPacket_t datRequest;
bool receivedDataRequest;

bool receivedColdStart;

static dataPacket_t dataPacket = {.type = data};
static uint8_t dataSequence = 0;

struct calibData deviceCalibration;

struct lcd_cmd display_cmd_buffer[64];

void packetTxConf(NWK_DataReq_t *req) {
	retransmit_cnt[req - nwkPacket]++;
	if ((req->status != NWK_SUCCESS_STATUS) && (req->status != NWK_NO_ROUTE_STATUS) && (retransmit_cnt[req-nwkPacket] < 10)) {
		retransmit_time[req-nwkPacket] = TCNT3 + 15 + (rand()/(RAND_MAX/(128*retransmit_cnt[req - nwkPacket])));
	}
	else {
		dataReqBusy[req - nwkPacket] = false;
		retransmit_time[req - nwkPacket] = 0;
	}
}

void handleDataRequest() {
	if (dataReady()) {
		dataSequence += 1;
		dataPacket.requestSequence = datRequest.requestSequence;
		getData(&dataPacket);
	
		uint8_t ind = 0;
		while (dataReqBusy[ind]) {
			SYS_TaskHandler();
			ind = (ind < (DATA_REQ_BUFFER_CNT - 1)) ? (ind+1) : 0;
		}
		nwkPacket[ind].dstAddr = baseStationList[connectedBaseStation].addr;
		nwkPacket[ind].dstEndpoint = APP_ENDPOINT;
		nwkPacket[ind].srcEndpoint = APP_ENDPOINT;
		nwkPacket[ind].options = NWK_OPT_ACK_REQUEST;
		nwkPacket[ind].data = (uint8_t *)(&dataPacket);
		nwkPacket[ind].size = sizeof(dataPacket_t);
		nwkPacket[ind].confirm = packetTxConf;
		dataReqBusy[ind] = true;
		retransmit_cnt[ind] = 1;
		retransmit_time[ind] = TCNT3 + 5 + (rand()/(RAND_MAX/(128*retransmit_cnt[ind]))); // Retransmit the packet at a random time in the future
		ui_updatePowerValues(&dataPacket);
	}
}

void handleDataAck(NWK_DataInd_t *packet) {
	if (packet->size != sizeof(dataAckPacket_t))
		return; // Not the right size for this kind of packet
	removeSamples(&dataPacket);
}

extern int16_t adcSampleData[4];
static bool rfReceivePacket(NWK_DataInd_t *ind) {
	// First figure out what kind of packet this is, and then call the appropreate function.
	switch ((packetType_t) (ind->data[0])) {
	case bacon:
		processBaconPacket(ind);
		break;
	case connectionAck:
		if(processConnectionAck(ind)) {
			ui_baseStationConnected();
			eeprom_update_block(&(baseStationList[connectedBaseStation]), (void*)27, sizeof(struct baseStation));
			eeprom_update_byte((uint8_t*)29, 1); // Force the RSSI of the connected base station to 1 without modifying value in ram.
			eeprom_update_byte((uint8_t*)26, 0xFF);
		}
		break;
	case dataRequest:
		if (ind->size != sizeof(dataRequestPacket_t))
			break;
		memcpy(&datRequest, ind->data, sizeof(dataRequestPacket_t));
		receivedDataRequest = true;
		return false;
		break;
	case dataAck:
		handleDataAck(ind);
		break;
	case coldStart:
		receivedColdStart = true;
		break;
	default:
		break;
	}

	return true;
}

	uint8_t counter = 0;
int main(void) {
	SYS_Init(); // Init Atmel Lightweight Mesh stack

	SYS_TaskHandler(); // Call the system task handler once before we configure the radio
	NWK_SetAddr(eeprom_read_word((uint16_t*)0));
	NWK_SetPanId(0); // Default PAN ID will be 0, can be changed using the set PAN command
	PHY_SetChannel(APP_CHANNEL);
	//NWK_SetSecurityKey(APP_SECURITY_KEY);
	PHY_SetRxState(true);
	NWK_OpenEndpoint(APP_ENDPOINT, rfReceivePacket);
	PHY_SetTxPower(0);

	// Seed the pseudorandom number generator
	srand(eeprom_read_word((uint16_t*)0));

	// Read eeprom data
	eeprom_read_block(&deviceCalibration, (void*)8, sizeof(deviceCalibration));
	if (eeprom_read_byte((uint8_t*)26)) { // There is valid data in the network information struct
		eeprom_read_block(baseStationList, (void*)27, sizeof(struct baseStation));
		uint8_t ch = 17;
		while ((baseStationList[0].name[ch] == ' ') || (baseStationList[0].name[ch] == '\0') || (baseStationList[0].name[ch] == 0xFF)) {
			baseStationList[0].name[ch] = ' ';
			ch -= 1;
		}
		baseStationList[0].nameLen = ch+1;
		baseStationListLength += 1;

		for (int cnt = 0; cnt < BASESTATION_LIST_SIZE; cnt++) {
			baseStationList[cnt].name[16] = ' ';
			baseStationList[cnt].name[17] = ' ';
		}
		sendConnectionRequest(0, &deviceCalibration);
	}	

	initDataAck();
	initLCD(display_cmd_buffer, 64);
	initUI();

	TCCR0B |= (1<<CS01);
	TCCR3B |= (1<<CS32) | (1<<CS30);

	sei();
	startDataAck();

	while (1) {
		SYS_TaskHandler();

		if (receivedDataRequest) {
			handleDataRequest();
			receivedDataRequest = false;
		}

		if (receivedColdStart) {
			if (connectedBaseStation == -1)
				sendConnectionRequest(0, &deviceCalibration);
			else
				sendConnectionRequest(connectedBaseStation, &deviceCalibration);
			ui_baseStationDisconnected();
			receivedColdStart = false;
		}

		updateUI();

		if (sampleCount > 40000) {
			if (dataPacket.sampleCount != 0)
				removeSamples(&dataPacket); // If the last transmitted data has not been acked then first remove the old data.
			getData(&dataPacket); // Sample new data
			ui_updatePowerValues(&dataPacket); // Update display
			removeSamples(&dataPacket); // Get rid of these samples now
		}
		
		if (TCNT0 > 80) {
			serviceLCD();
			TCNT0 = 0;
		}

		TCCR3B &= ~((1<<CS32) | (1<<CS30));
		if (TCNT3 != 0) {
			for (uint8_t cnt = 0; cnt < DATA_REQ_BUFFER_CNT; cnt++) {
				if (dataReqBusy[cnt] && (retransmit_time[cnt] != 0)) {
					if (retransmit_time[cnt] <= TCNT3) {
						NWK_DataReq(&(nwkPacket[cnt]));
						retransmit_time[cnt] = 0;
					}
					else
						retransmit_time[cnt] -= TCNT3;
				}
			}
		}
		TCNT3 = 0;
		TCCR3B |= (1<<CS32) | (1<<CS30);
	}
}

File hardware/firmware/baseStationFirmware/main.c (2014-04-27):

#include <avr/io.h>
#include <avr/eeprom.h>
#include <util/delay.h>
#include <stdint.h>

#include "config.h"
#include "hal.h"
#include "phy.h"
#include "sys.h"
#include "nwk.h"
#include "sysTimer.h"

#include "uart.h"

#include "protocol.h"
#include "../remoteMonitorFirmware/protocol.h"

#define DATA_REQ_BUFFER_CNT 32

static NWK_DataReq_t txPacket[DATA_REQ_BUFFER_CNT];
static bool dataReqBusy[DATA_REQ_BUFFER_CNT];

uint8_t uart_tx_buf[512];
uint8_t uart_rx_buf[512];
uint8_t packet_buf[128];

uint16_t currentPAN;

static void packetTxConf(NWK_DataReq_t *req) {
	dataReqBusy[req - txPacket] = false;
}
		
static bool rfReceivePacket(NWK_DataInd_t *ind) {
	rxHeader_t packetHeader;
	packetHeader.size = ind->size;
	packetHeader.sourceAddr = ind->srcAddr;
	packetHeader.rssi = ind->rssi;
	uart_tx_data((uint8_t*)(&packetHeader), sizeof(rxHeader_t));
	uart_tx_data(ind->data, ind->size);
	return true;
}

int main(void) {
	uint16_t counter = 0;

	SYS_Init(); // Init Atmel Lightweight Mesh stack

	SYS_TaskHandler(); // Call the system task handler once before we configure the radio
	NWK_SetAddr(eeprom_read_word((uint16_t*)0));
	NWK_SetPanId(0); // Default PAN ID will be 0, can be changed using the set PAN command
	PHY_SetChannel(APP_CHANNEL);
	//NWK_SetSecurityKey(APP_SECURITY_KEY);
	PHY_SetRxState(true);
	NWK_OpenEndpoint(APP_ENDPOINT, rfReceivePacket);
	PHY_SetTxPower(0);
	currentPAN = 0;

	uart_init_port(uart_baud_115200, uart_tx_buf, 512, uart_rx_buf, 512); // Init uart

	// Configure onboard LED as output
	DDRB |= 1<<4;
	PORTB |= 1<<4;

	// Configure analog switch for antenna
	DDRG |= 1<<1;
	DDRF |= 1<<2;
	PORTG |= 1<<1;
	PORTF &= ~(1<<2);
	
	while (1) {
		SYS_TaskHandler();
		
		// Flash the LED so we can tell if something has frozen up
		if (counter == 4092) {
			PORTB ^= (1<<4);
			counter = 0;
		}
		else
			counter ++;
			

		// Parse received uart packets, if we get one, then transmit it to the RF network
		if (uart_received_bytes() == 0) /* no bytes, just continue */
			continue;
		
		if (uart_received_bytes() > 0) {
			switch (uart_rx_peek(0)) {
			case sizeof(baconPacket_t):
			case sizeof(connectionRequestPacket_t):
			case sizeof(connectionAckPacket_t):
			case sizeof(dataRequestPacket_t):
			case sizeof(dataPacket_t):
				break; // If we are any of these lengths, then continue
			default: // Otherwise flush the buffers and continue
				uart_rx_flush();
				continue;
			}

			if ((uart_rx_peek(0) + sizeof(txHeader_t)) <= uart_received_bytes()) {
				txHeader_t packetHeader;
				uart_rx_data(&packetHeader, sizeof(txHeader_t));
				uart_rx_data(packet_buf, packetHeader.size);
	
				// Switch PANs if needed			
				if (packetHeader.PAN_ID != currentPAN) {
					NWK_SetPanId(packetHeader.PAN_ID);
					currentPAN = packetHeader.PAN_ID;
					SYS_TaskHandler();
				}
	
				uint8_t ind = 0;
				while (dataReqBusy[ind]) {
					SYS_TaskHandler();
					ind = (ind < (DATA_REQ_BUFFER_CNT-1)) ? (ind+1) : 0;
				}
	
				if (packetHeader.PANBroadcast == 0)
					txPacket[ind].options = 0;
				else
					txPacket[ind].options = NWK_OPT_BROADCAST_PAN_ID;
	
				txPacket[ind].dstAddr = packetHeader.destAddr;
				txPacket[ind].dstEndpoint = APP_ENDPOINT;
				txPacket[ind].srcEndpoint = APP_ENDPOINT;
				txPacket[ind].data = packet_buf;
				txPacket[ind].size = packetHeader.size;
				txPacket[ind].confirm = packetTxConf;
				NWK_DataReq(&(txPacket[ind]));
				dataReqBusy[ind] = true;
			}
		}
	}
}

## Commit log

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2013-11-23 Added ATMEGA245RFR2 part to PADs part library and started schematic for remote monitor.
    [remoteMonitor.sch]
2013-11-23 Added ferrite bead component to library and drew up power filtering schematic.
    [remoteMonitor.sch]
2013-11-23 Added balun to library and schematic.
    [remoteMonitor.sch]
2013-11-26 Added antenna, crystal and reset hardware to microcontroller.
    [remoteMonitor.sch]
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2013-11-26 Added programming header.
    [remoteMonitor.sch]
2013-11-26 Added interfaces for remote monitor unit peripherals to scheamatic.
    [remoteMonitor.sch]
2013-11-26 Rearranged remote monitoring unit shcematic a little.
    [remoteMonitor.sch]
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2013-11-26 Changed PI filter components to 0402s so the pads better match the transmision line length. Routed out transmission line section.
    [remoteMonitor.sch]
2013-11-26 Setup keepouts for ground plane.
    [remoteMonitor.sch]
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2013-12-14 Added a bunch of components to the parts library. Still need to add PCB drawings for the parts.
    [remoteMonitor.sch]
2013-12-14 Renamed reference designators with a prefix for the block number they are a part of.
    [remoteMonitor.sch]
2013-12-15 Added PCB decals for all power supply block components. Added power supply schematic to remote monitoring unit schematic.
    [remoteMonitor.sch]
2013-12-15 Added voltage reference block to unified remote monitoring unit schematic.
    [remoteMonitor.sch]
2013-12-15 Added NEMA5-15 connectors to schematic.
    [remoteMonitor.sch]
2013-12-15 Added current sensing to schematic.
    [remoteMonitor.sch]
2013-12-15 Added voltage attenuator to remote monitoring unit shematic.
    [remoteMonitor.sch]
2013-12-15 Added zero-cross detector to schematic.
    [remoteMonitor.sch]
2013-12-15 Added ADC block to remote monitoring unit shcematic.
    [remoteMonitor.sch]
2013-12-15 Added display to remote monitoring unit schematic.
    [remoteMonitor.sch]
2013-12-15 Added buttons block to schematic.
    [remoteMonitor.sch]
2013-12-15 Created PDF of completed remote monitoring unit schematic.
    [remoteMonitor.sch]
2013-12-15 Fixed sheet titles, somehow they all got set to the same thing.
    [remoteMonitor.sch]
2013-12-16 Working on PCB layout for remote monitoring unit.
    [remoteMonitor.sch]
2013-12-16 More work on the remote monitoring unit PCB design. The high voltage section is complete, I'm now working on laying out the analog section.
    [remoteMonitor.sch]
2013-12-17 Analog section of remote monitor about 90% layed out.
    [remoteMonitor.sch]
2013-12-17 Added two more decoupling capacitors to ADC to decouple the pins on both sides of the chip.
    [remoteMonitor.sch]
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2013-12-17 Starting to figure out space required for digital section. It looks like we may need need less space than initally thought.
    [remoteMonitor.sch]
2013-12-17 More digital layout. Moved push button inputs to F0-2 instead of F5-7 to move them farther away from the RF circuitry.
    [remoteMonitor.sch]
2013-12-17 Fixed PDF of remote monitor schematic. Because there were some dumb mistakes.
2013-12-17 More work on digital and RF section. Nearing final placements of components.
    [remoteMonitor.sch]
2013-12-18 Finished routing remote monitoring unit PCB. There are a few clearance violations to fix, but it should be pretty good.
    [remoteMonitor.sch]
2013-12-18 Forgot to save everything.
    [remoteMonitor.sch]
2013-12-18 Still didn't manage to commit the latest revision.
    [remoteMonitor.sch]
2013-12-19 Fixed resistors in voltage attenuator section because Berkeley pointed out they were completely wrong.
    [remoteMonitor.sch]
2013-12-19 Fixed silkscreen and design rule violations on remote monitor. Unless there mistakes found, the board should be done.
    [remoteMonitor.sch]
2013-12-19 Fixed transmission line trace to account for DFRobot manufacturing processs.
    [remoteMonitor.sch]
2013-12-19 Added logo and board info to bottom silk screen.
    [remoteMonitor.sch]
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2013-12-29 Fixed bugs in base station firmware.
    [main.c]
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2014-01-11 Added CAM files to the repo. Wasn't sure if I should, but it seemded like other people might want access to them.
    [remoteMonitor.GBL, remoteMonitor.GBO, remoteMonitor.GBP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]
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2014-01-12 jqPlot Library
    [KCPsample4.csv]
2014-01-12 Test code to communicate with ADC. This code seems to work, and is now stuck forever on the first prototype board.
    [main.c]
2014-01-13 Removed documentation and examples
    [KCPsample4.csv]
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2014-01-16 Unrolled data unpacking loop for a bit extra speed. Disabling and re-enabling interrupts is not the responsibility of this driver and can cause issues in certain situations, so this was also removed.
    [adc.c]
2014-01-16 Fixed a few bugs in data acquisition code. Mainly that the pin change interrupt flag needed to be cleared in the interrupt.
    [dataAck.c]
2014-01-17 Case Solidworks Files
    [c-3-213598-2-m-3d.stp, case.SLDASM, pcb.SLDPRT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]
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2014-01-18 Holes + Locations
    [case.SLDASM, pcb.SLDPRT]
2014-01-18 Case rev1 done
    [base.SLDPRT, case.SLDASM, cover.SLDPRT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]
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2014-01-19 Replaced programMAC.py script with a new one, programConfig.py, which reads in a board configuration file, and programs a Mega's eeprom. The configuration file contains both network information and c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
2014-01-19 Fixed one bug in eeprom code.
    [main.c]
2014-01-19 Fixed bug which prevented transmission of current scaling value on channel 2.
2014-01-19 Fixes to base station firmware to make restoration of base station information from eeprom work better.
    [main.c]
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2014-01-20 Fixed sutter in uart driver.
    [uart.c]
2014-01-20 Revert "Added Timing Padding"
    This reverts commit acad58d622af0523df3004f669ffa5e314da9f23.
    [network_manager.py]
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2014-01-27 Bug fixes to adc data acquisition tester.
    [main.c]
2014-01-30 Print files
    [case.SLDASM, printed - base-1.STL, printed - cover-1.STL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]
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2014-02-02 DB no longer global
    [network_manager.py]
2014-02-02 Linux Debug Part VIII
    Also fixed the KeyError if a data request is responded to before a cold
    start
    [network_manager.py]
2014-02-02 Fixed errors on Windows
    new connection opening in each process
    [network_manager.py]
2014-02-02 Reworked data transmission firmware. Every 4th AC cycle is ignored to allow more time for RF communication. Average is cleared after 20 seconds if no data request is received.
    [dataAck.c, main.c]
2014-02-07 Fixed some bugs in the LCD code. It's still not working, but I don't know if it's hardware or firmware issue.
    [lcd.c, main.c]
2014-02-09 More work on the UI. This may have broken some things, still working on it.
    [main.c]
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2014-02-09 Fixed display code for power measurement. Values are now padded with spaces out to 5 characters. Additionally, power measurements are properly rounded now.
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2014-02-10 Bug fix to button test demo. Added testing program for RF interface.
    [main.c]
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2014-02-14 Remote monitoring unit UI now scrolls the base station network name if it does not fit on the screen.
    [main.c]
2014-02-14 Button testing program now has the correct direction logic.
    [main.c]
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2014-02-15 programConfig script was broken and would program both channels with the first channel's calibration values.
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2014-02-16 Made second revision modifications to remote monitoring unit schematic.
    [remoteMonitor.sch]
2014-02-17 Finished making board changes for rev2 design.
    [remoteMonitor.sch]
2014-02-17 Final fixes to rev 2 remote monitoring unit board. Generated new CAM files.
    [remoteMonitor.sch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]
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2014-02-17 Forgot to save schematic before comitting.
    [remoteMonitor.sch]
2014-02-17 Cover tweaks
    Moved button holes and widened friction fit.
    [cover.SLDPRT]
2014-02-17 Bug fixes to both remote monitoring unit data acquisition firmware as well as calibration too.
    [calibrateRMU.py, dataAck.c]
2014-02-18 More modifications to remote monitoring PCB rev 2. Split up input jacks again, now we have two voltage attenuators, but they are located so one can be disabled if not in use.
    [remoteMonitor.sch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]
2014-02-18 Zero crossing detector now is triggered off the lower outlet, the same one which the power supply operates off. This ensures that the if the power is on the zero cross detector will have a signal to 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
    [remoteMonitor.sch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]
2014-02-19 Final modifications to rev 2 board.
    [remoteMonitor.sch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]
2014-02-20 Capacitor was marked with incorrect value.
    [remoteMonitor.sch]
2014-02-27 Added a logo and re-did the printer files
    [base.SLDPRT, case.SLDASM, cover.SLDPRT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]
2014-03-02 Attempts at bug fixes.
    I don't currently have hardware to test with, but I believe this will fix the reporting of power data in the absense of data requests. Additionally, this fixes a bug in RF packet data transmission buffer.
    [dataAck.c, main.c]
2014-03-02 Fixed bug in RF packet transmission buffer.
    I'm not sure if this was what was limiting the packet transmission rate from the base station, I will have to test that when I have access to hardware. However, regardless, it was a memory overrun issue and needed to be fixed.
    [main.c]
2014-03-02 Fixes issue #4: invalid readings with no data request.
    The bug was caused by old data values being removed from the running sum
    twice in certain situations. Resolving this issue, reported values
    appear to always be correct now.
    This also fixes syntax errors in the previous commit and removes
    decimals from inital display.
    [main.c]
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2014-03-02 This improves the high speed transmission of packets from the base station. There are, however, still problems with transmitting large numbers of packets sequentially.
    [main.c]
2014-03-04 One more modification to improve receive timing of base station interface microcontroller. It is now working well enough that I think we can close the issue. Fixes #5
    [uart.c]
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2014-03-08 More fixes to migrate firmware to revision 2 remote monitoring unit board.
    [dataAck.c]
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2014-03-11 Fixes display bug for large power values.
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2014-03-27 Added bill of materials CSV for remote monitoring unit.
    [BillOfMaterials.csv]
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2014-03-30 Added fuse make target, program boards with correct fuses.
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2014-04-07 Remote monitoring unit now explicitly requests ack packet.
    For some reason the base station stack seemed to be ignoring some packets unless they explicitly requested an ack. With this fix, I have not seen any dropped packets.
    [main.c]
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2014-04-15 One file for Library
    [printed.SLDASM, printed.STL]
2014-04-15 Fixes to the calibration script.
    [calibrateRMU.py]
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2014-04-17 Fleshing out the full 3D model of the remote monitoring unit.
    [Screen.SLDPRT, Switch.SLDPRT, case.SLDASM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]
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2014-04-18 Error handling & Printouts
    [network_manager.py]
2014-04-18 Fixed bug in remote monitoring unit firmware which caused a stack overflow hanging the device.
    [main.c]
2014-04-27 Modification to improve cold start behavior. Does not entirely solve this problem.
    [main.c]
2014-04-27 Adds another check for divide by zero errors.
    [network_manager.py]
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
